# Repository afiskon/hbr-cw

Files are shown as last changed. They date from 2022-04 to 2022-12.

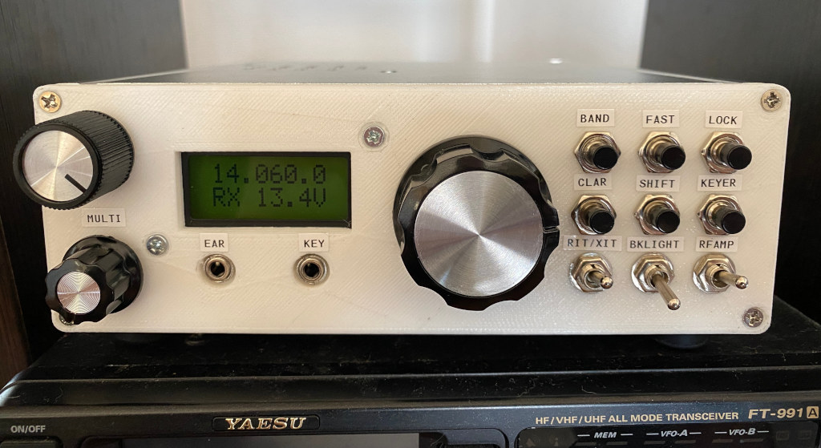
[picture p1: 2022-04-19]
images/front-panel.jpg

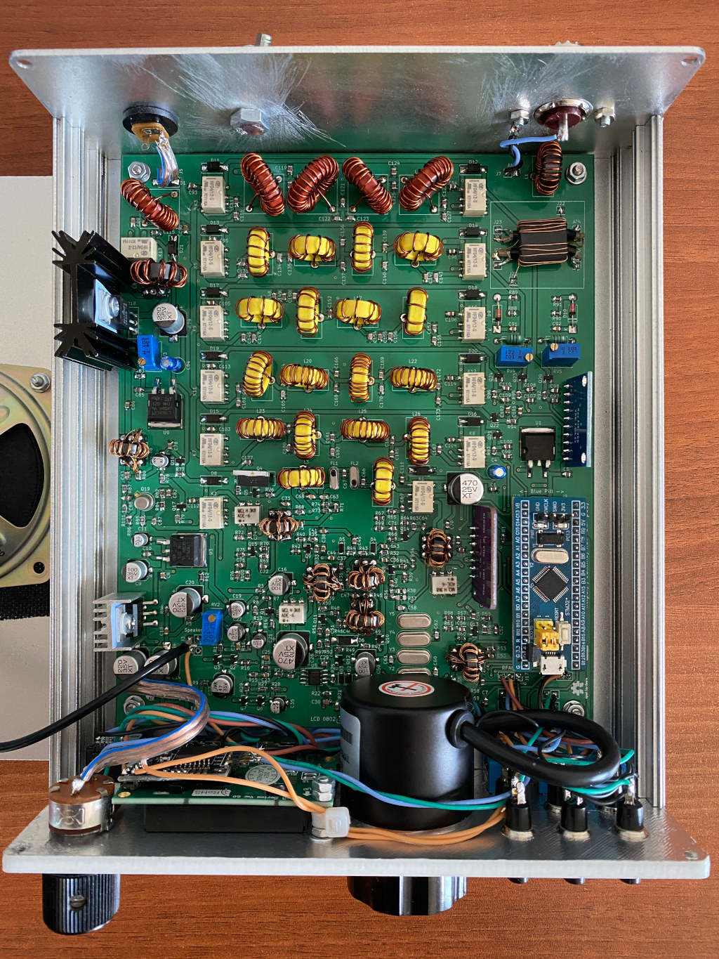
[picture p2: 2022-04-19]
images/internals.jpg

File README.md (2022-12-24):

# HBR/CW

**Update**: The project has some issues with spurious signals. This problem was addressed in [HBR/3B](https://github.com/afiskon/hbr-3b) and [HBR/8B](https://github.com/afiskon/hbr-8b).

All HF bands QRP CW transceiver

* Covers 80, 40, 30, 20, 17, 15, 12 and 10 meter bands
* IF-derived AGC
* Supports RIT, XIT and SHIFT
* 10-30 WPM Elekey-B type keyer + straight key mode
* Keyer settings are saved in EEPROM
* 5W class C power amplifier
* 9-pole low-pass filters
* HIGH SWR indicator
* Open-source firmware and hardware

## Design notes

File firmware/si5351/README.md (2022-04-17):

# stm32-si5351

HAL-based Si5351 driver for STM32.

Main respository: https://github.com/afiskon/stm32-si5351

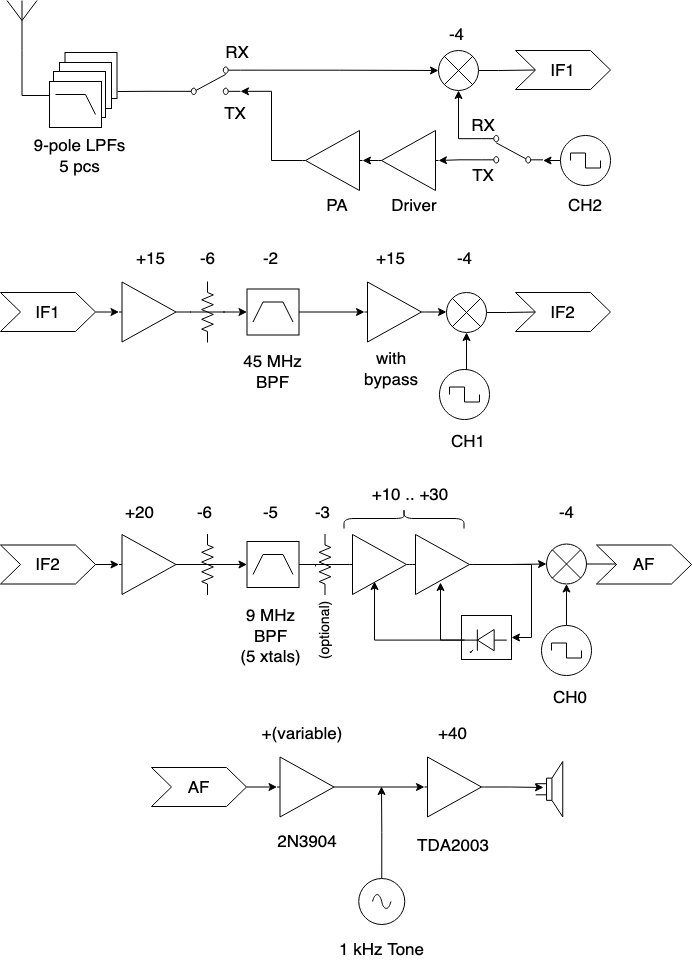
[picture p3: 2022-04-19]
block-diagram/hbr-cw-block-diagram.png

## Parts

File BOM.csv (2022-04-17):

Reference | Quantity | Value | Footprint
C1 C5 C6 C7 C8 C10 C15 C17 C29 C31 C33 C36 C37 C38 C39 C40 C41 C42 C43 C44 C45 C46 C47 C49 C51 C52 C53 C54 C55 C56 C64 C65 C69 C70 C71 C72 C73 C74 C75 C76 C78 C80 C81 C82 C83 C85 C86 C87 C88 C93 C94 C95 C96 C97 C98 C99 C100 C101 C102 C103 C104 C105 C106 C107 C108 C109 C110 C111 C112 C113 C114 C115 | 72 | 0.1u | Capacitor_SMD:C_0805_2012Metric_Pad1.15x1.40mm_HandSolder
C11 C21 C32 | 3 | 10u | Capacitor_SMD:CP_Elec_4x5.4
C119 C120 C124 C125 C179 C181 C185 | 7 | 820p | Capacitor_SMD:C_0805_2012Metric_Pad1.15x1.40mm_HandSolder
C12 C77 | 2 | 1u | Capacitor_SMD:CP_Elec_4x5.4
C121 C123 | 2 | 680p | Capacitor_SMD:C_0805_2012Metric_Pad1.15x1.40mm_HandSolder
C122 | 1 | 390p | Capacitor_SMD:C_0805_2012Metric_Pad1.15x1.40mm_HandSolder
C131 C143 C165 C170 | 4 | 150p | Capacitor_SMD:C_0805_2012Metric_Pad1.15x1.40mm_HandSolder
C132 C135 C139 C142 C150 C154 | 6 | 10p | Capacitor_SMD:C_0805_2012Metric_Pad1.15x1.40mm_HandSolder
C146 C148 C149 C155 C156 C158 | 6 | 100p | Capacitor_SMD:C_0805_2012Metric_Pad1.15x1.40mm_HandSolder
C147 C157 C162 C172 | 4 | 18p | Capacitor_SMD:C_0805_2012Metric_Pad1.15x1.40mm_HandSolder
C152 C161 C166 C168 C173 | 5 | 220p | Capacitor_SMD:C_0805_2012Metric_Pad1.15x1.40mm_HandSolder
C18 C24 C25 | 3 | 47n | Capacitor_SMD:C_0805_2012Metric_Pad1.15x1.40mm_HandSolder
C182 | 1 | 56p | Capacitor_SMD:C_0805_2012Metric_Pad1.15x1.40mm_HandSolder
C19 C22 | 2 | 22u | Capacitor_SMD:CP_Elec_5x5.4
C2 C26 | 2 | 470u | Capacitor_SMD:CP_Elec_10x10.5
C13 C14 C20 C79 | 4 | 220u | Capacitor_SMD:CP_Elec_8x10.5
C23 C91 C92 | 3 | 0.01u | Capacitor_SMD:C_0805_2012Metric_Pad1.15x1.40mm_HandSolder
C27 | 1 | 47u | Capacitor_SMD:CP_Elec_6.3x5.8
C28 C30 | 2 | 4.7n | Capacitor_SMD:C_0805_2012Metric_Pad1.15x1.40mm_HandSolder
C35 | 1 | 4.7u | Capacitor_SMD:CP_Elec_4x5.4
C4 C84 | 2 | 0.33u | Capacitor_THT:C_Radial_D5.0mm_H5.0mm_P2.00mm
C48 C116 C117 C127 C128 C177 C187 | 7 | 470p | Capacitor_SMD:C_0805_2012Metric_Pad1.15x1.40mm_HandSolder
C57 C58 C59 C60 C61 C62 C134 C136 C140 C164 C169 | 11 | 270p | Capacitor_SMD:C_0805_2012Metric_Pad1.15x1.40mm_HandSolder
C63 C66 C137 C180 C184 | 5 | 22p | Capacitor_SMD:C_0805_2012Metric_Pad1.15x1.40mm_HandSolder
C67 | 1 | 8p | Capacitor_SMD:C_0805_2012Metric_Pad1.15x1.40mm_HandSolder
C68 | 1 | 2p | Capacitor_SMD:C_0805_2012Metric_Pad1.15x1.40mm_HandSolder
C89 C90 | 2 | 1000p | Capacitor_SMD:C_0805_2012Metric_Pad1.15x1.40mm_HandSolder
C9 C16 C50 | 3 | 100u | Capacitor_SMD:CP_Elec_6.3x7.7
D1 D6 | 2 | SS14 | Diode_SMD:D_SMA_Handsoldering
D9 D10 | 2 | 1N34/D9B/D311 | Diode_THT:D_DO-41_SOD81_P10.16mm_Horizontal
D2 D3 D4 D5 | 4 | 1N4148W | Diode_SMD:D_SOD-123
D7 D8 D11 D12 D13 D14 D15 D16 D17 D18 D19 D20 D21 | 13 | M7 | Diode_SMD:D_SMA_Handsoldering
FL1 FL2 | 2 | 45M15B (*) | Crystal:Resonator-3Pin_W7.0mm_H2.5mm
H1 H2 H3 H4 | 4 | MH | MountingHole:MountingHole_3.2mm_M3_Pad_Via
J1 | 1 | ON/OFF | Connector_PinHeader_2.54mm:PinHeader_1x02_P2.54mm_Vertical
J10 | 1 | BluePill_Right | Connector_PinSocket_2.54mm:PinSocket_1x20_P2.54mm_Vertical
J11 | 1 | MAIN | Connector_PinHeader_2.54mm:PinHeader_1x04_P2.54mm_Vertical
J12 | 1 | BAND | Connector_PinHeader_2.54mm:PinHeader_1x02_P2.54mm_Vertical
J13 | 1 | LCD 0802 | Connector_PinHeader_2.54mm:PinHeader_1x04_P2.54mm_Vertical
J14 | 1 | RIT/XIT | Connector_PinSocket_2.54mm:PinSocket_1x03_P2.54mm_Vertical
J15 | 1 | FAST | Connector_PinHeader_2.54mm:PinHeader_1x02_P2.54mm_Vertical
J16 | 1 | LOCK | Connector_PinHeader_2.54mm:PinHeader_1x02_P2.54mm_Vertical
J17 | 1 | RFAMP | Connector_PinSocket_2.54mm:PinSocket_1x03_P2.54mm_Vertical
J18 | 1 | CLAR | Connector_PinHeader_2.54mm:PinHeader_1x02_P2.54mm_Vertical
J19 | 1 | Si5351 | Connector_PinHeader_2.54mm:PinHeader_1x07_P2.54mm_Vertical
J2 | 1 | SPEAKER_IN | Connector_PinHeader_2.54mm:PinHeader_1x02_P2.54mm_Vertical
J20 | 1 | SHIFT | Connector_PinHeader_2.54mm:PinHeader_1x02_P2.54mm_Vertical
J21 | 1 | KEYER | Connector_PinHeader_2.54mm:PinHeader_1x02_P2.54mm_Vertical
J22 | 1 | GND_B | Connector_PinHeader_2.54mm:PinHeader_1x01_P2.54mm_Vertical
J23 | 1 | STK_A | Connector_PinHeader_2.54mm:PinHeader_1x02_P2.54mm_Vertical
J24 | 1 | STK_B | Connector_PinHeader_2.54mm:PinHeader_1x02_P2.54mm_Vertical
J25 | 1 | STK_C | Connector_PinHeader_2.54mm:PinHeader_1x02_P2.54mm_Vertical
J26 | 1 | STK_D | Connector_PinHeader_2.54mm:PinHeader_1x02_P2.54mm_Vertical
J27 | 1 | ADS1115 | Connector_PinSocket_2.54mm:PinSocket_1x10_P2.54mm_Vertical
J28 | 1 | GND_C | Connector_PinHeader_2.54mm:PinHeader_1x01_P2.54mm_Vertical
J29 | 1 | VOL | Connector_PinSocket_2.54mm:PinSocket_1x03_P2.54mm_Vertical
J3 | 1 | SPEAKER_OUT | Connector_PinHeader_2.54mm:PinHeader_1x02_P2.54mm_Vertical
J4 | 1 | EAR | Connector_PinSocket_2.54mm:PinSocket_1x03_P2.54mm_Vertical
J5 | 1 | VCC | Connector_PinHeader_2.54mm:PinHeader_1x02_P2.54mm_Vertical
J6 | 1 | KEY | Connector_PinSocket_2.54mm:PinSocket_1x03_P2.54mm_Vertical
J7 | 1 | ANT | Connector_PinHeader_2.54mm:PinHeader_1x02_P2.54mm_Vertical
J8 | 1 | MULTI | Connector_PinHeader_2.54mm:PinHeader_1x04_P2.54mm_Vertical
J9 | 1 | BluePill_Left | Connector_PinSocket_2.54mm:PinSocket_1x20_P2.54mm_Vertical
K1 K2 K3 K4 K5 K6 K7 K8 K9 K10 K11 K12 K13 | 13 | HFD4/12S | Relay_SMD:Relay_DPDT_Omron_G6K-2F-Y
L1 | 1 | 23T @ FT50-43 | Inductor_THT:L_Toroid_Vertical_L13.0mm_W6.5mm_P5.60mm
L11 L14 | 2 | 0.5u | Inductor_THT:L_Toroid_Vertical_L13.0mm_W6.5mm_P5.60mm
L15 L18 | 2 | 0.35u | Inductor_THT:L_Toroid_Vertical_L13.0mm_W6.5mm_P5.60mm
L16 L17 | 2 | 0.4u | Inductor_THT:L_Toroid_Vertical_L13.0mm_W6.5mm_P5.60mm
L19 L22 | 2 | 0.7u | Inductor_THT:L_Toroid_Vertical_L13.0mm_W6.5mm_P5.60mm
L2 L12 L13 | 3 | 0.6u | Inductor_THT:L_Toroid_Vertical_L13.0mm_W6.5mm_P5.60mm
L20 L21 | 2 | 0.8u | Inductor_THT:L_Toroid_Vertical_L13.0mm_W6.5mm_P5.60mm
L23 L26 | 2 | 1.4u | Inductor_THT:L_Toroid_Vertical_L13.0mm_W6.5mm_P5.60mm
L24 L25 | 2 | 1.6u | Inductor_THT:L_Toroid_Vertical_L13.0mm_W6.5mm_P5.60mm
L3 | 1 | 0.65u | Inductor_THT:L_Toroid_Vertical_L13.0mm_W6.5mm_P5.60mm
L4 L5 | 2 | 1000 uH | Inductor_THT:L_Axial_L6.6mm_D2.7mm_P10.16mm_Horizontal_Vishay_IM-2
L6 | 1 | 3.6u | Inductor_THT:L_Radial_L12.6mm_W12.6mm_Px9.52mm_Py9.52mm_Pulse_LP-37
L7 L10 | 2 | 2.9u | Inductor_THT:L_Radial_L12.6mm_W12.6mm_Px9.52mm_Py9.52mm_Pulse_LP-37
L8 L9 | 2 | 3.2u | Inductor_THT:L_Radial_L12.6mm_W12.6mm_Px9.52mm_Py9.52mm_Pulse_LP-37
Q1 Q5 Q8 Q9 Q10 Q11 Q12 Q13 Q14 Q15 Q17 Q20 Q21 Q22 Q23 Q24 | 16 | MMBT3904 | Package_TO_SOT_SMD:SOT-23
Q16 | 1 | MMBT3906 | Package_TO_SOT_SMD:SOT-23
Q18 | 1 | RD15HVF1 | Package_TO_SOT_THT:TO-220-3_Vertical
Q19 | 1 | 2N2369A/КТ3142A (*) | Package_TO_SOT_THT:TO-18-3
Q2 Q3 Q6 Q7 | 4 | MMBF170 | Package_TO_SOT_SMD:SOT-23
Q4 | 1 | IRF4905 | Package_TO_SOT_THT:TO-220-3_Vertical
R1 | 1 | 15K | Resistor_SMD:R_0805_2012Metric_Pad1.15x1.40mm_HandSolder
R6 R9 R12 R27 R81 | 5 | 10 | Resistor_SMD:R_0805_2012Metric_Pad1.15x1.40mm_HandSolder
R13 | 1 | 47K | Resistor_SMD:R_0805_2012Metric_Pad1.15x1.40mm_HandSolder
R14 R39 R40 R43 R44 R50 R57 R65 R72 R78 R85 | 11 | 1K | Resistor_SMD:R_0805_2012Metric_Pad1.15x1.40mm_HandSolder
R15 | 1 | 51 | Resistor_SMD:R_0805_2012Metric_Pad1.15x1.40mm_HandSolder
R7 R10 R11 R16 R28 R83 | 6 | 2.2K | Resistor_SMD:R_0805_2012Metric_Pad1.15x1.40mm_HandSolder
R17 R19 R29 | 3 | 10K | Resistor_SMD:R_0805_2012Metric_Pad1.15x1.40mm_HandSolder
R2 | 1 | 2.7K | Resistor_SMD:R_0805_2012Metric_Pad1.15x1.40mm_HandSolder
R18 R21 | 2 | 33K | Resistor_SMD:R_0805_2012Metric_Pad1.15x1.40mm_HandSolder
R22 R32 R33 R46 R54 R63 R69 R82 | 8 | 3.3K | Resistor_SMD:R_0805_2012Metric_Pad1.15x1.40mm_HandSolder
R23 | 1 | 6.8K | Resistor_SMD:R_0805_2012Metric_Pad1.15x1.40mm_HandSolder
R25 | 1 | 8.2K | Resistor_SMD:R_0805_2012Metric_Pad1.15x1.40mm_HandSolder
R26 R77 R79 R92 R93 R94 R95 R96 | 8 | 470 | Resistor_SMD:R_0805_2012Metric_Pad1.15x1.40mm_HandSolder
R3 R30 R31 R88 R89 R90 R91 | 7 | 100 | Resistor_SMD:R_0805_2012Metric_Pad1.15x1.40mm_HandSolder
R34 R35 | 2 | 820 | Resistor_SMD:R_0805_2012Metric_Pad1.15x1.40mm_HandSolder
R36 | 1 | 18 | Resistor_SMD:R_0805_2012Metric_Pad1.15x1.40mm_HandSolder
R37 R38 | 2 | 300 | Resistor_SMD:R_0805_2012Metric_Pad1.15x1.40mm_HandSolder
R4 | 1 | 220 | Resistor_SMD:R_0805_2012Metric_Pad1.15x1.40mm_HandSolder
R41 R42 R51 R60 R66 R75 R86 | 7 | 68 | Resistor_SMD:R_0805_2012Metric_Pad1.15x1.40mm_HandSolder
R45 R53 R62 R68 R80 | 5 | 22 | Resistor_SMD:R_0805_2012Metric_Pad1.15x1.40mm_HandSolder
R48 R55 R64 R70 R84 | 5 | 1.3K | Resistor_SMD:R_0805_2012Metric_Pad1.15x1.40mm_HandSolder
R47 R49 | 2 | 4.7K | Resistor_SMD:R_0805_2012Metric_Pad1.15x1.40mm_HandSolder
R5 | 1 | 680 | Resistor_SMD:R_0805_2012Metric_Pad1.15x1.40mm_HandSolder
R52 R61 R67 R76 R87 R97 R98 R99 R100 R101 | 10 | 12 | Resistor_SMD:R_0805_2012Metric_Pad1.15x1.40mm_HandSolder
R56 R71 | 2 | 36 | Resistor_SMD:R_0805_2012Metric_Pad1.15x1.40mm_HandSolder
R58 R59 R73 R74 | 4 | 150 | Resistor_SMD:R_0805_2012Metric_Pad1.15x1.40mm_HandSolder
R8 R20 R24 | 3 | 100K | Resistor_SMD:R_0805_2012Metric_Pad1.15x1.40mm_HandSolder
RV2 RV3 | 2 | 10K | Potentiometer_THT:Potentiometer_Bourns_3296W_Vertical
RV4 RV5 | 2 | 1K | Potentiometer_THT:Potentiometer_Bourns_3296W_Vertical
SYM1 | 1 | Logo_Open_Hardware_Small | Symbol:OSHW-Logo2_9.8x8mm_SilkScreen
SYM2 | 1 | SYM_Radio_Waves_Large | Symbol:KiCad-Logo_5mm_SilkScreen
T1 T2 T3 T4 T5 T6 T8 | 7 | FT37-43 | Package_DIP:DIP-6_W7.62mm
T7 | 1 | FT50-43 | Package_DIP:DIP-6_W7.62mm
U1 U9 | 2 | L7805 | Package_TO_SOT_SMD:TO-263-2
U2 | 1 | 24LC64 | Package_SO:SO-8_5.3x6.2mm_P1.27mm
U3 | 1 | L7809 | Package_TO_SOT_SMD:TO-263-2
U4 | 1 | TDA2003 | Package_TO_SOT_THT:TO-220-5_P3.4x3.7mm_StaggerOdd_Lead3.8mm_Vertical
U5 | 1 | NE5532 | Package_SO:SOIC-8_5.23x5.23mm_P1.27mm
U6 U7 U8 | 3 | ADE-6 | RF_Mini-Circuits:Mini-Circuits_CD542_LandPatternPL-052
Y1 Y2 Y3 Y4 Y5 | 5 | 9Mhz | Crystal:Crystal_HC49-U_Vertical
~ | 1 | BN61-202
~ | 1 | MCP100-315DI

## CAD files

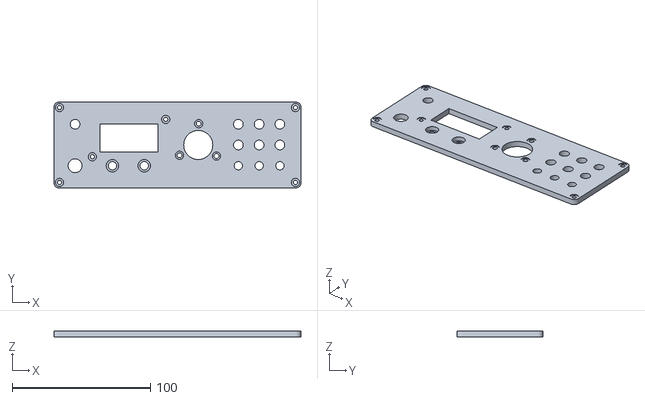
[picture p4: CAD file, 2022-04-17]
front-panel/optical-encoders.stl
178.5 x 62.0 x 4.00

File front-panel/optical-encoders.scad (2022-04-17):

W = 178.5;
H = 62;
t = 4;

pot_dia = 7; // volume control
jack_dia = 6; // 3.5 mm jack
jack_nut_dia = 9;
jack_nut_height = t-1;
button_dia = 7; // button
toggle_dia = 6; // toggle switch
corner_dia = 7;
screw_dia = 3;
screw_offset = 4;
screw2_dia = 6;
screw2_height = 0.5;
eps = 0.01;

main_enc_dia = 21;
main_enc_screws_dia = 15;
main_enc_screws_dist = 7;
main_enc_rotate_delta = 12;
main_enc_screw_dia = 3.5;
multi_enc_dia = 10;

// LCD info
LCD_W = 58;
LCD_H = 32;
lcd_offset_y = 8;
lcd_offset_x = 6;
lcd_h = LCD_H - lcd_offset_x*2;
lcd_w = LCD_W - lcd_offset_y*2;

hole_dia = 3;
hole_offset_x = 1+hole_dia/2;
hole_offset_y = 1+hole_dia/2;

module rounded_cube( width, height, dia, t ) {
    translate([-width/2, -height/2, -t/2])
        linear_extrude(height = t)
            hull() {
                translate([dia/2, dia/2, 0])
                    circle(d = dia, $fn = 25, center = true);
                translate([dia/2, height - dia/2, 0 ])
                    circle(d = dia, $fn = 25, center = true);
                translate([width - dia/2, height - dia/2, 0])
                    circle(d = dia, $fn = 25, center = true);
                translate([width - dia/2, dia/2, 0])
                    circle(d = dia, $fn = 25, center = true);
            }
}

difference() {
    rounded_cube(W, H, corner_dia, t);
    
    // screws
    translate([-W/2+screw_offset, H/2-screw_offset, 0]) {
        cylinder(d = screw_dia, h = t*2, $fn = 25, center = true);
        translate([0, 0, (t-screw2_height)/2+eps])
            cylinder(d = screw2_dia, h = screw2_height+eps, $fn = 25, center = true);
    }
    translate([-W/2+screw_offset, -H/2+screw_offset, 0]) {
        cylinder(d = screw_dia, h = t*2, $fn = 25, center = true);
        translate([0, 0, (t-screw2_height)/2+eps])
            cylinder(d = screw2_dia, h = screw2_height+eps, $fn = 25, center = true);
    }
    translate([W/2-screw_offset, H/2-screw_offset, 0]) {
        cylinder(d = screw_dia, h = t*2, $fn = 25, center = true);
        translate([0, 0, (t-screw2_height)/2+eps])
            cylinder(d = screw2_dia, h = screw2_height+eps, $fn = 25, center = true);
    }
    
    translate([W/2-screw_offset, -H/2+screw_offset, 0]) {
        cylinder(d = screw_dia, h = t*2, $fn = 25, center = true);
        translate([0, 0, (t-screw2_height)/2+eps])
            cylinder(d = screw2_dia, h = screw2_height+eps, $fn = 25, center = true);
    }
    
    // volume control and MULTI knob    
    translate([-74, 15, 0])
        cylinder(d = pot_dia, h = t*2, $fn = 50, center = true);
    translate([-74, -15, 0])
        cylinder(d = multi_enc_dia, h = t*2, $fn = 50, center = true);
    
    // LCD
    translate([-35, 5, 0]) rotate([0, 0, 90]) {
        cube([lcd_h, lcd_w, t*2], center=true);
        /*translate([LCD_H/2-hole_offset_x, LCD_W/2-hole_offset_y, 0]) {
            cylinder(h = t*2, d = hole_dia, center = true, $fn = 25);
            translate([0, 0, (t-screw2_height)/2+eps])
                cylinder(d = screw2_dia, h = screw2_height+eps, $fn = 25, center = true);
        }*/
        translate([-LCD_H/2+hole_offset_x, LCD_W/2-hole_offset_y, 0]) {
            cylinder(h = t*2, d = hole_dia, center = true, $fn = 25);
            translate([0, 0, (t-screw2_height)/2+eps])
                cylinder(d = screw2_dia, h = screw2_height+eps, $fn = 25, center = true);
        }
        translate([LCD_H/2-hole_offset_x, -LCD_W/2+hole_offset_y, 0]) {
            cylinder(h = t*2, d = hole_dia, center = true, $fn = 25);
            translate([0, 0, (t-screw2_height)/2+eps])
                cylinder(d = screw2_dia, h = screw2_height+eps, $fn = 25, center = true);
        }
        /* translate([-LCD_H/2+hole_offset_x, -LCD_W/2+hole_offset_y, 0]) {
            cylinder(h = t*2, d = hole_dia, center = true, $fn = 25);
            translate([0, 0, (t-screw2_height)/2+eps])
                cylinder(d = screw2_dia, h = screw2_height+eps, $fn = 25, center = true);
        } */
    }
    
    // 3.5 mm jacks
    translate([-24, -15, 0]) {
        cylinder(d = jack_dia, h = t*2, $fn = 50, center = true);
        translate([0, 0, (t - jack_nut_height)/2+eps])
            cylinder(d = jack_nut_dia, h = jack_nut_height, $fn = 50, center = true);
    }
    translate([-47, -15, 0]) {
        cylinder(d = jack_dia, h = t*2, $fn = 50, center = true);
        translate([0, 0, (t - jack_nut_height)/2+eps])
            cylinder(d = jack_nut_dia, h = jack_nut_height, $fn = 50, center = true);
    }
    
    // Main dial
    translate([15, 0, 0]) {
        cylinder(d = main_enc_dia, h = t*2, $fn = 50, center = true);
        
        rotate([0,0,120*0 + main_enc_rotate_delta]) {
            translate([main_enc_screws_dist/2, main_enc_screws_dia, 0]) {
                cylinder(d = main_enc_screw_dia, h = t*2, $fn = 25, center = true);
                translate([0, 0, (t-screw2_height)/2+eps])
                    cylinder(d = screw2_dia, h = screw2_height+eps, $fn = 25, center = true);
            }
            
            /*translate([-main_enc_screws_dist/2, main_enc_screws_dia,0]) {
                cylinder(d = main_enc_screw_dia, h = t*2, $fn = 25, center = true);
                translate([0, 0, (t-screw2_height)/2+eps])
                    cylinder(d = screw2_dia, h = screw2_height+eps, $fn = 25, center = true);
            }*/
        }
        
        rotate([0,0,120*1 + main_enc_rotate_delta]) {
            translate([main_enc_screws_dist/2, main_enc_screws_dia, 0]) {
                cylinder(d = main_enc_screw_dia, h = t*2, $fn = 25, center = true);
                translate([0, 0, (t-screw2_height)/2+eps])
                    cylinder(d = screw2_dia, h = screw2_height+eps, $fn = 25, center = true);
            }
            
            /*translate([-main_enc_screws_dist/2, main_enc_screws_dia,0]) {
                cylinder(d = main_enc_screw_dia, h = t*2, $fn = 25, center = true);
                translate([0, 0, (t-screw2_height)/2+eps])
                    cylinder(d = screw2_dia, h = screw2_height+eps, $fn = 25, center = true);
            }*/
        }
        
        rotate([0,0,120*2 + main_enc_rotate_delta]) {
            translate([main_enc_screws_dist/2, main_enc_screws_dia, 0]) {
                cylinder(d = main_enc_screw_dia, h = t*2, $fn = 25, center = true);
                translate([0, 0, (t-screw2_height)/2+eps])
                    cylinder(d = screw2_dia, h = screw2_height+eps, $fn = 25, center = true);
            }
            
            /*translate([-main_enc_screws_dist/2, main_enc_screws_dia,0]) {
                cylinder(d = main_enc_screw_dia, h = t*2, $fn = 25, center = true);
                translate([0, 0, (t-screw2_height)/2+eps])
                    cylinder(d = screw2_dia, h = screw2_height+eps, $fn = 25, center = true);
            }*/
        }
    }
    
    // Buttons and toggles
    translate([74, 0, 0]) {
        cylinder(d = button_dia, h = t*2, $fn = 50, center = true);
        
        translate([0, 15, 0])
            cylinder(d = button_dia, h = t*2, $fn = 50, center = true);
        
        translate([0, -15, 0])
            cylinder(d = toggle_dia, h = t*2, $fn = 50, center = true);
    }
    
    translate([74-15, 0, 0]) {
        cylinder(d = button_dia, h = t*2, $fn = 50, center = true);
        
        translate([0, 15, 0])
            cylinder(d = button_dia, h = t*2, $fn = 50, center = true);
        
        translate([0, -15, 0])
            cylinder(d = toggle_dia, h = t*2, $fn = 50, center = true);
    }
    
    translate([74-15*2, 0, 0]) {
        cylinder(d = button_dia, h = t*2, $fn = 50, center = true);
        
        translate([0, 15, 0])
            cylinder(d = button_dia, h = t*2, $fn = 50, center = true);
        
        translate([0, -15, 0])
            cylinder(d = toggle_dia, h = t*2, $fn = 50, center = true);
    }
}

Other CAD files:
front-panel/pec11r-encoders.stl
front-panel/pec11r-encoders.scad

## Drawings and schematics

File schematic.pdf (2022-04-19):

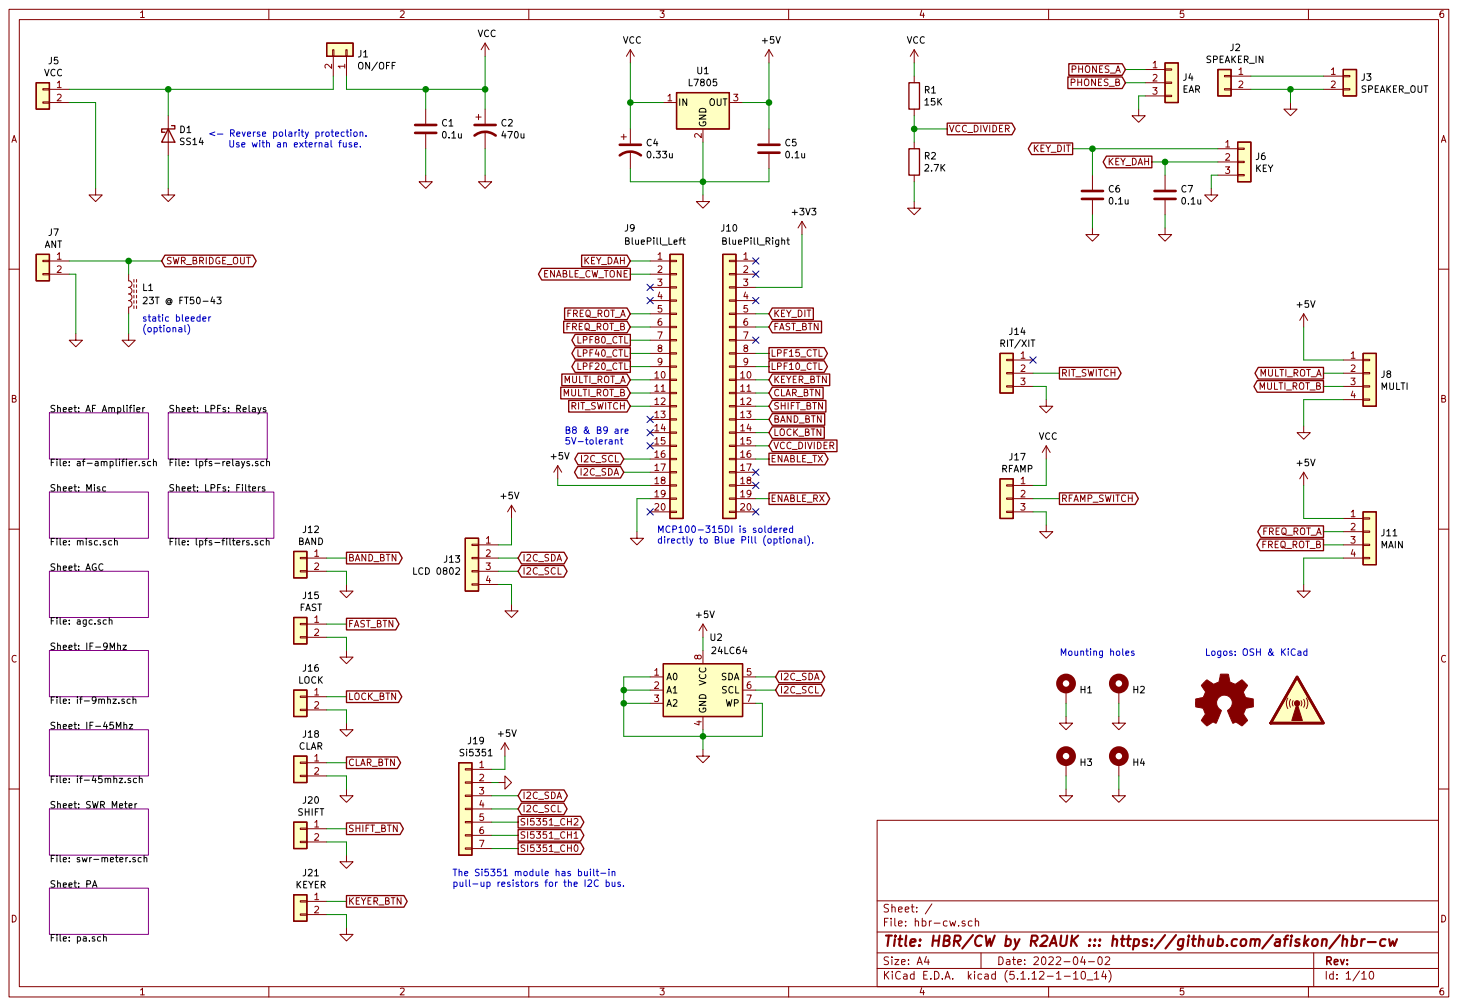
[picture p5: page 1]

< Reverse polarity protection.
Use with an external fuse.

File: af-amplifier.sch Sheet: Misc File: misc.sch Sheet: AGC

File: lpfs-relays.sch Sheet: LPFs: Filters File: lpfs-filters.sch

File: agc.sch Sheet: IF-9Mhz File: if-9mhz.sch Sheet: IF-45Mhz File: if-45mhz.sch Sheet: PA

4 SDA 5 SCL 6 WP 7 VCC

File: pa.sch Sheet: SWR Meter File: swr-meter.sch

pull-up resistors for the I2C bus.

File: hbr-cw.sch Sheet: /
Id: 1/10 Title: HBR/CW by R2AUK ::: https://github.com/afiskon/hbr-cw

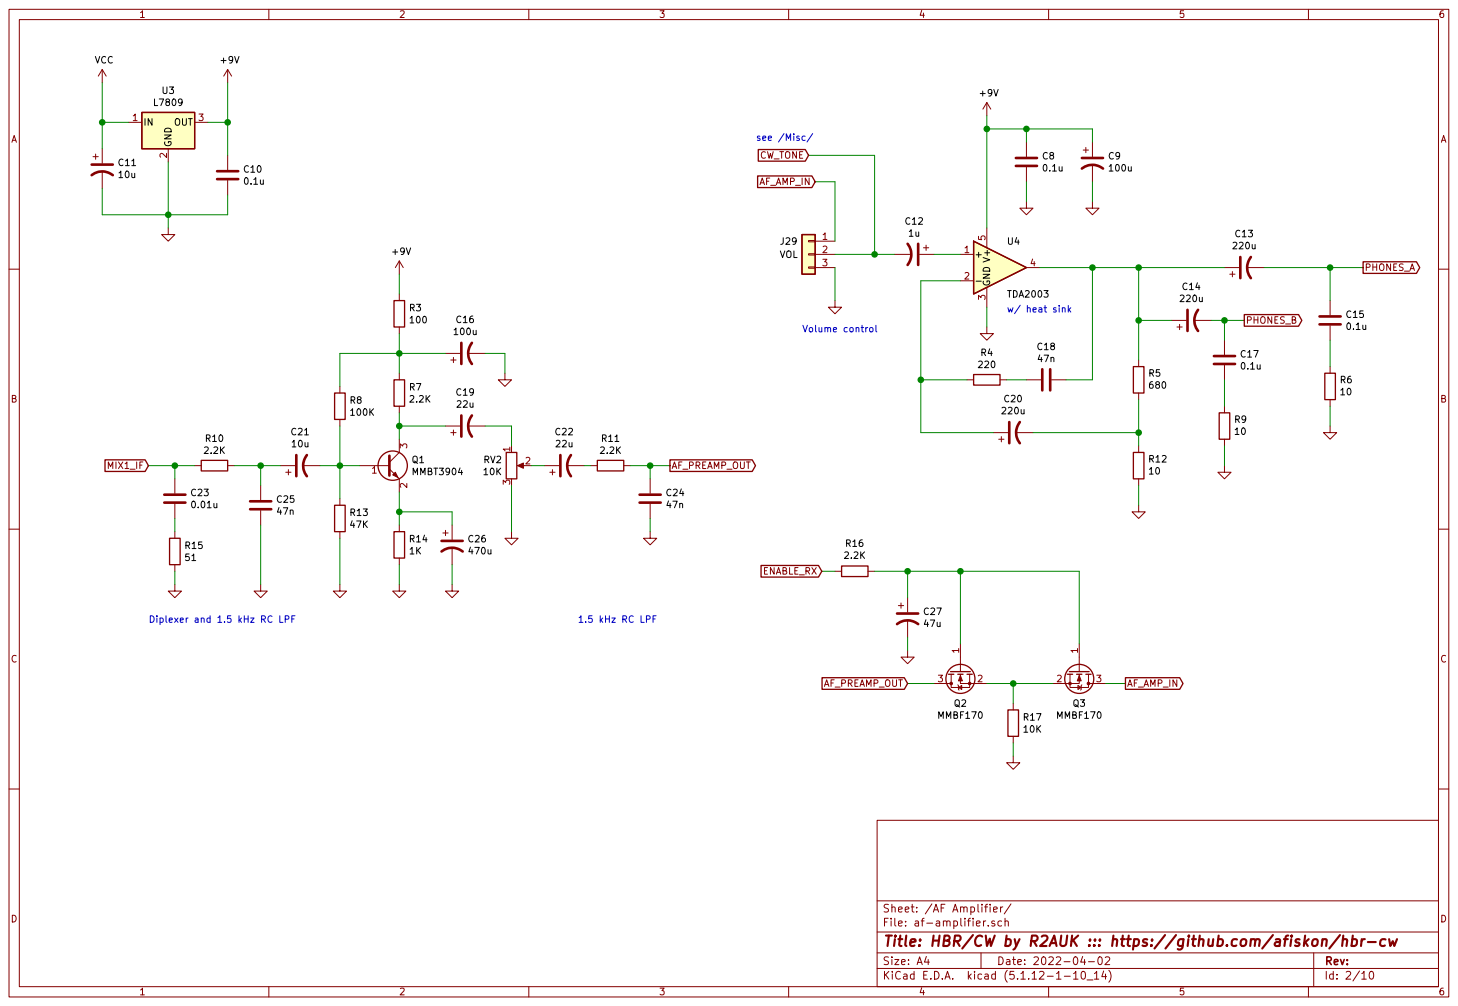
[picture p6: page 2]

see /Misc/ Volume control
CW_TONE

Sheet: /AF Amplifier/
File: af-amplifier.sch
Id: 2/10 Title: HBR/CW by R2AUK ::: https://github.com/afiskon/hbr-cw

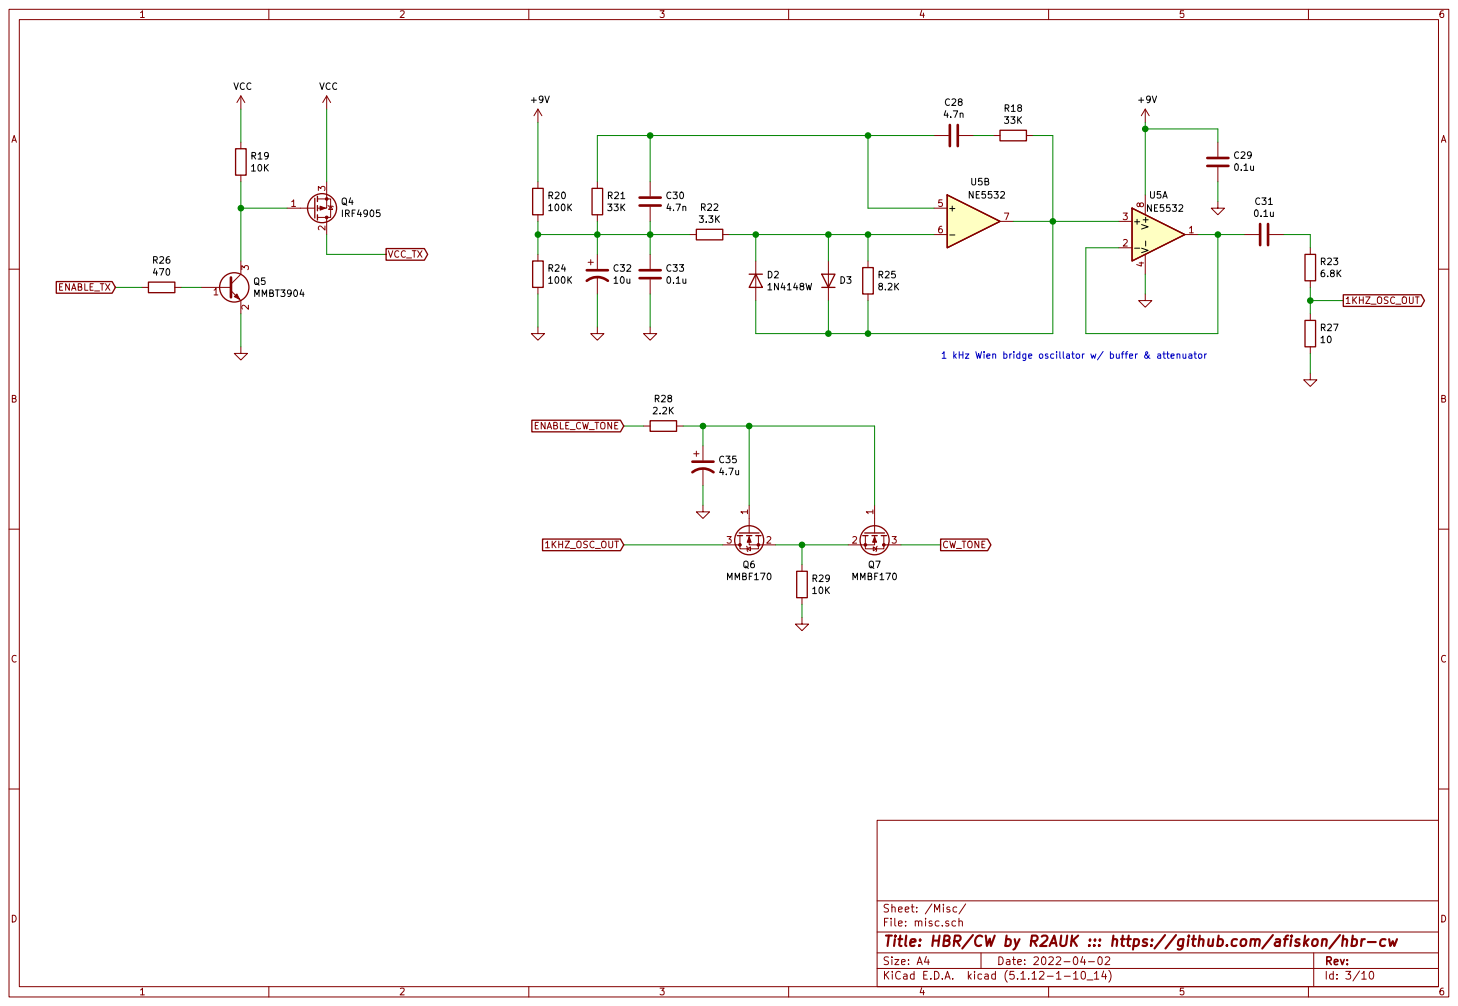
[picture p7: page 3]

1 kHz Wien bridge oscillator w/ buffer & attenuator

File: misc.sch Sheet: /Misc/
Id: 3/10 Title: HBR/CW by R2AUK ::: https://github.com/afiskon/hbr-cw

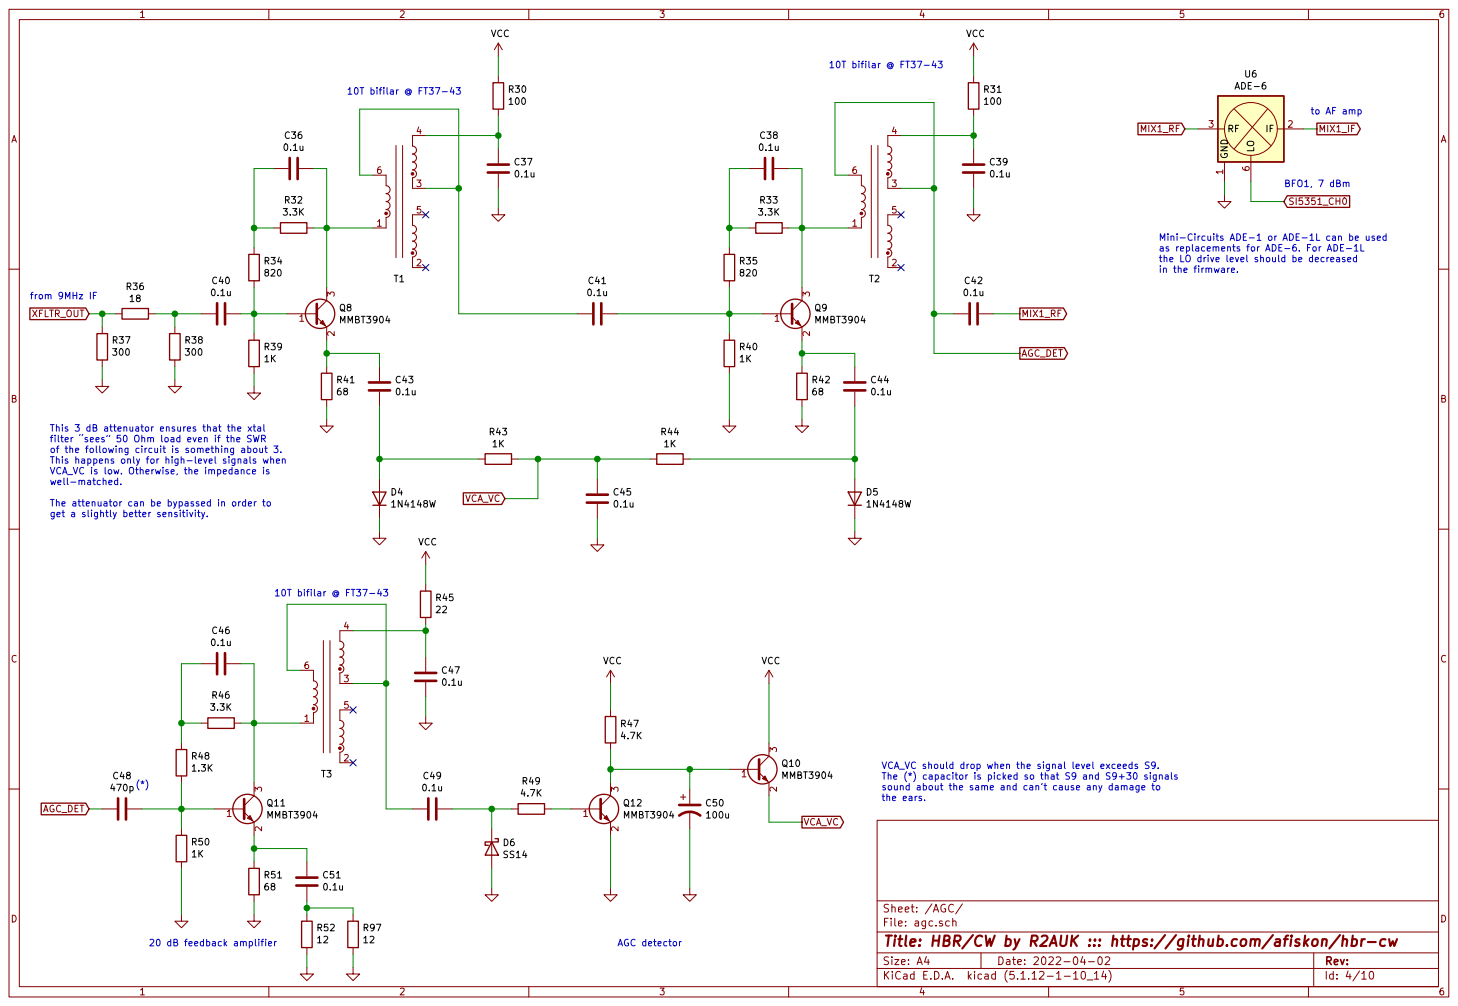
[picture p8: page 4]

in the firmware. 10T bifilar @ FT37-43

Mini-Circuits ADE-1 or ADE-1L can be used
as replacements for ADE-6. For ADE-1L
the LO drive level should be decreased

This 3 dB attenuator ensures that the xtal filter sees 50 Ohm load even if the SWR

of the following circuit is something about 3.
This happens only for high-level signals when
VCA_VC is low. Otherwise, the impedance is well-matched. The attenuator can be bypassed in order to

File: agc.sch Sheet: /AGC/ R46

VCA_VC should drop when the signal level exceeds S9.
The (*) capacitor is picked so that S9 and S9+30 signals
sound about the same and cant cause any damage to
the ears.

Id: 4/10 Title: HBR/CW by R2AUK ::: https://github.com/afiskon/hbr-cw

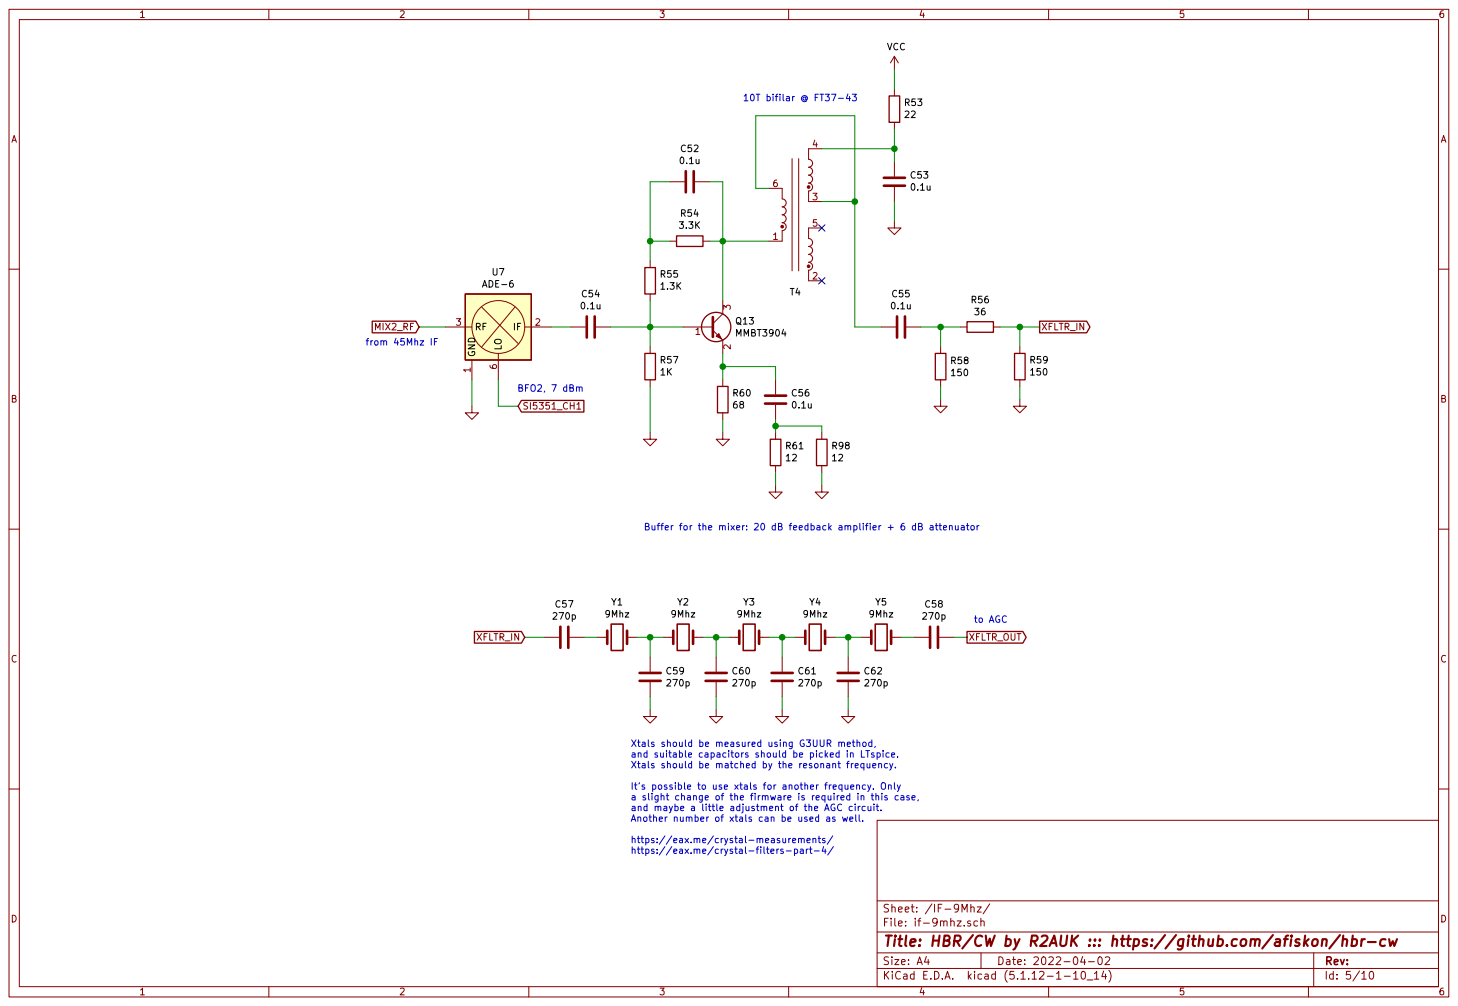
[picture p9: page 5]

File: if-9mhz.sch Sheet: /IF-9Mhz/ GND

Buffer for the mixer: 20 dB feedback amplifier + 6 dB attenuator

Xtals should be measured using G3UUR method,
and suitable capacitors should be picked in LTspice.
Xtals should be matched by the resonant frequency.

Its possible to use xtals for another frequency. Only
a slight change of the firmware is required in this case,
and maybe a little adjustment of the AGC circuit. Another number of xtals can be used as well. https://eax.me/crystal-measurements/

https://eax.me/crystal-filters-part-4/

Id: 5/10 Title: HBR/CW by R2AUK ::: https://github.com/afiskon/hbr-cw

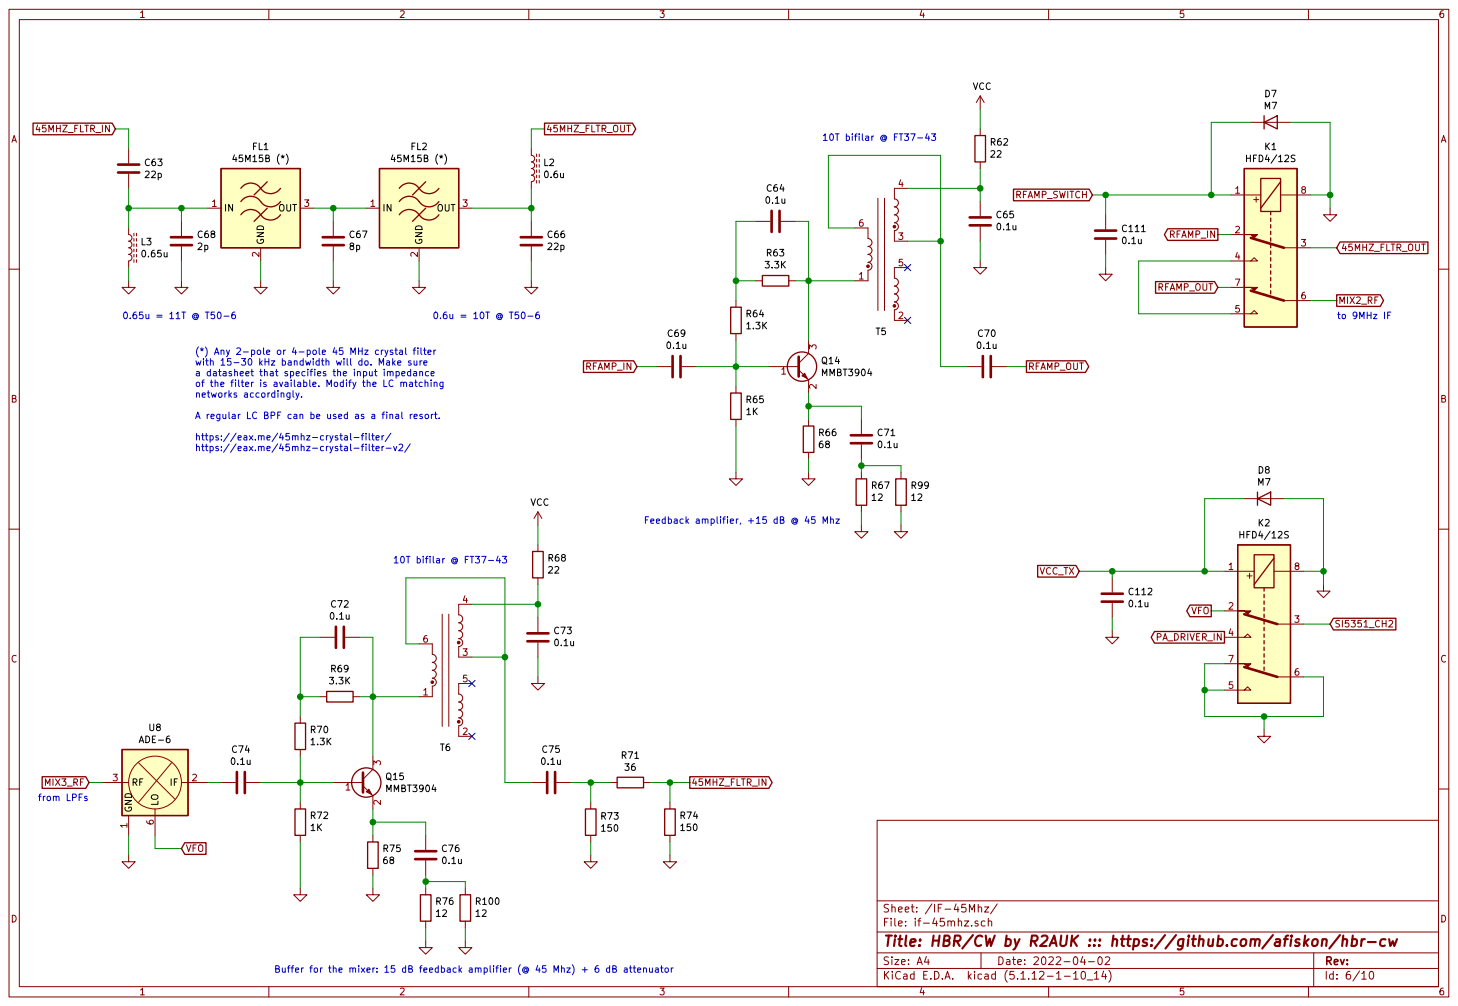
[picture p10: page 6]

(*) Any 2-pole or 4-pole 45 MHz crystal filter with 15-30 kHz bandwidth will do. Make sure

a datasheet that specifies the input impedance
of the filter is available. Modify the LC matching
networks accordingly.

A regular LC BPF can be used as a final resort.

https://eax.me/45mhz-crystal-filter/

Feedback amplifier, +15 dB @ 45 Mhz

10T bifilar @ FT37-43 Buffer for the mixer: 15 dB feedback amplifier (@ 45 Mhz) + 6 dB attenuator

Id: 6/10 Title: HBR/CW by R2AUK ::: https://github.com/afiskon/hbr-cw

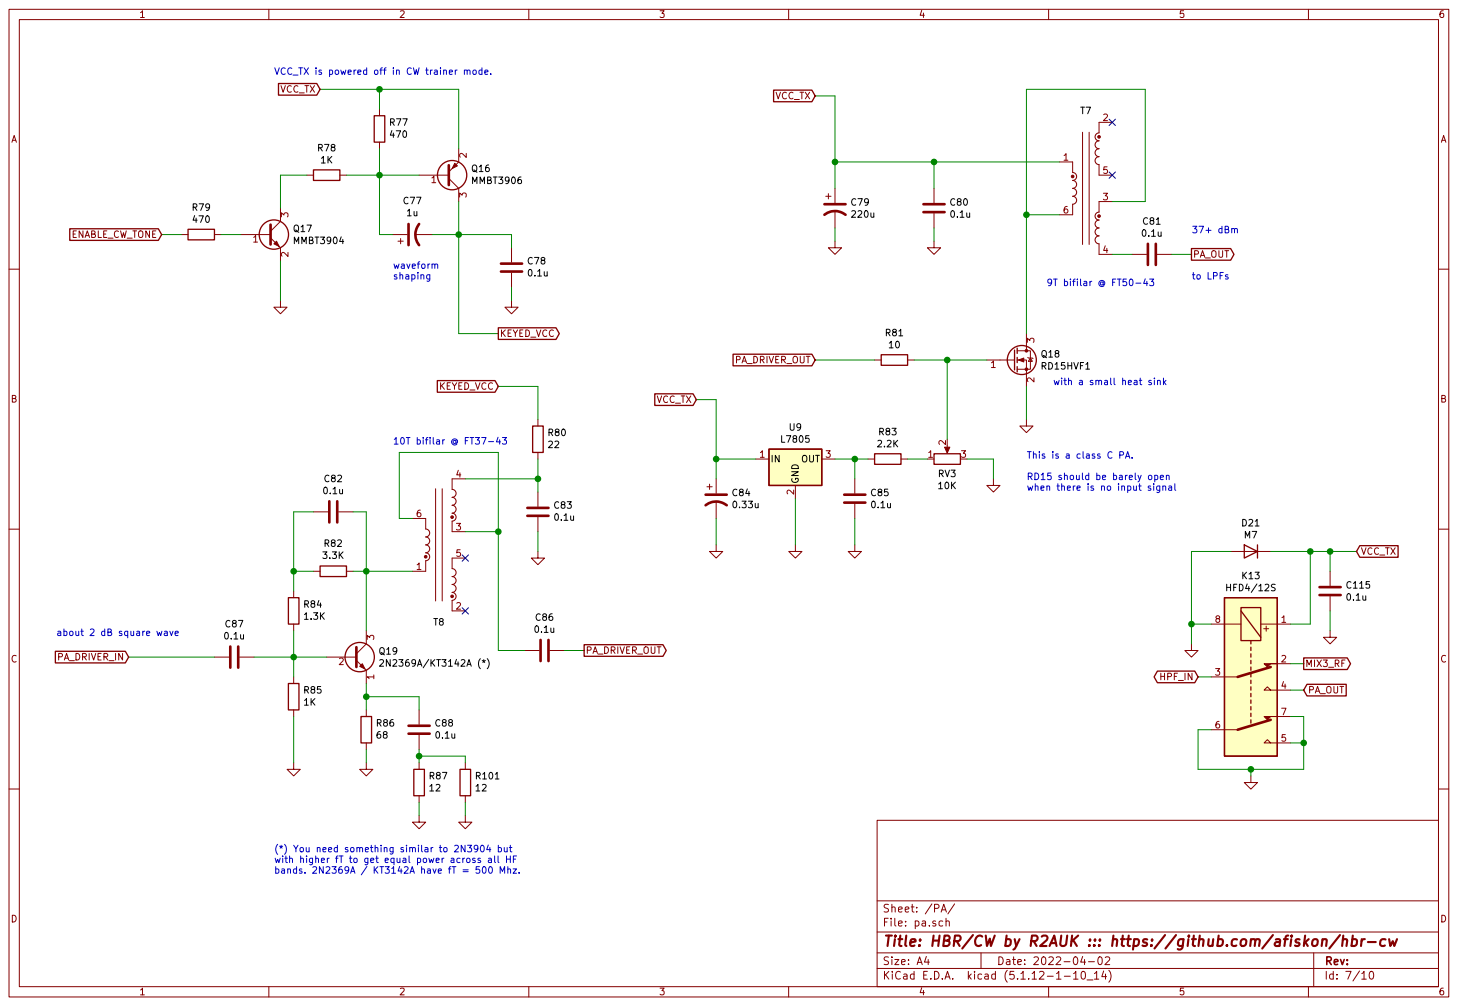
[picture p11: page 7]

when there is no input signal

about 2 dB square wave

(*) You need something similar to 2N3904 but
with higher fT to get equal power across all HF
bands. 2N2369A / KT3142A have fT = 500 Mhz.

Id: 7/10 Title: HBR/CW by R2AUK ::: https://github.com/afiskon/hbr-cw

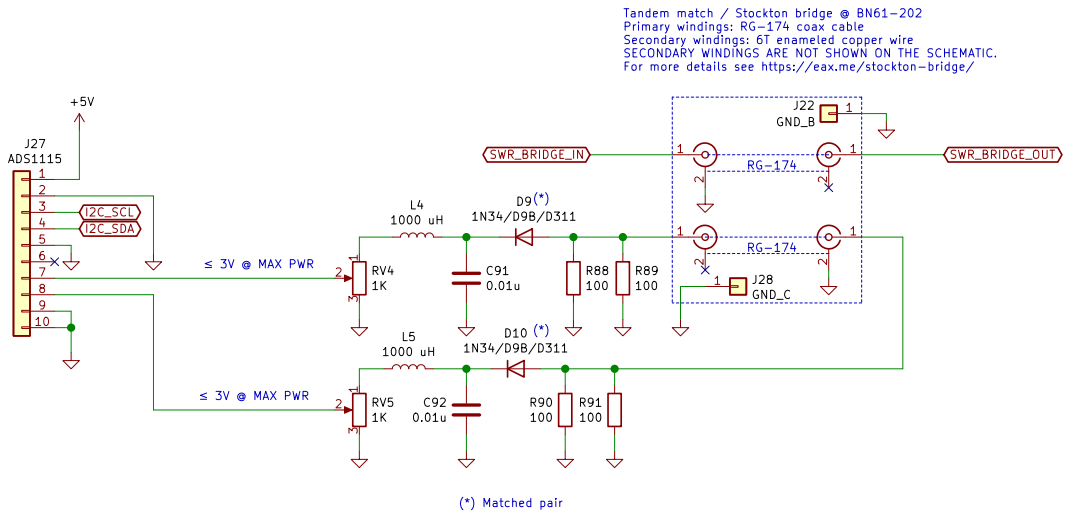
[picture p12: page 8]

Tandem match / Stockton bridge @ BN61-202
Primary windings: RG-174 coax cable
Secondary windings: 6T enameled copper wire SECONDARY WINDINGS ARE NOT SHOWN ON THE SCHEMATIC. For more details see https://eax.me/stockton-bridge/

File: swr-meter.sch Sheet: /SWR Meter/
Id: 8/10 Title: HBR/CW by R2AUK ::: https://github.com/afiskon/hbr-cw

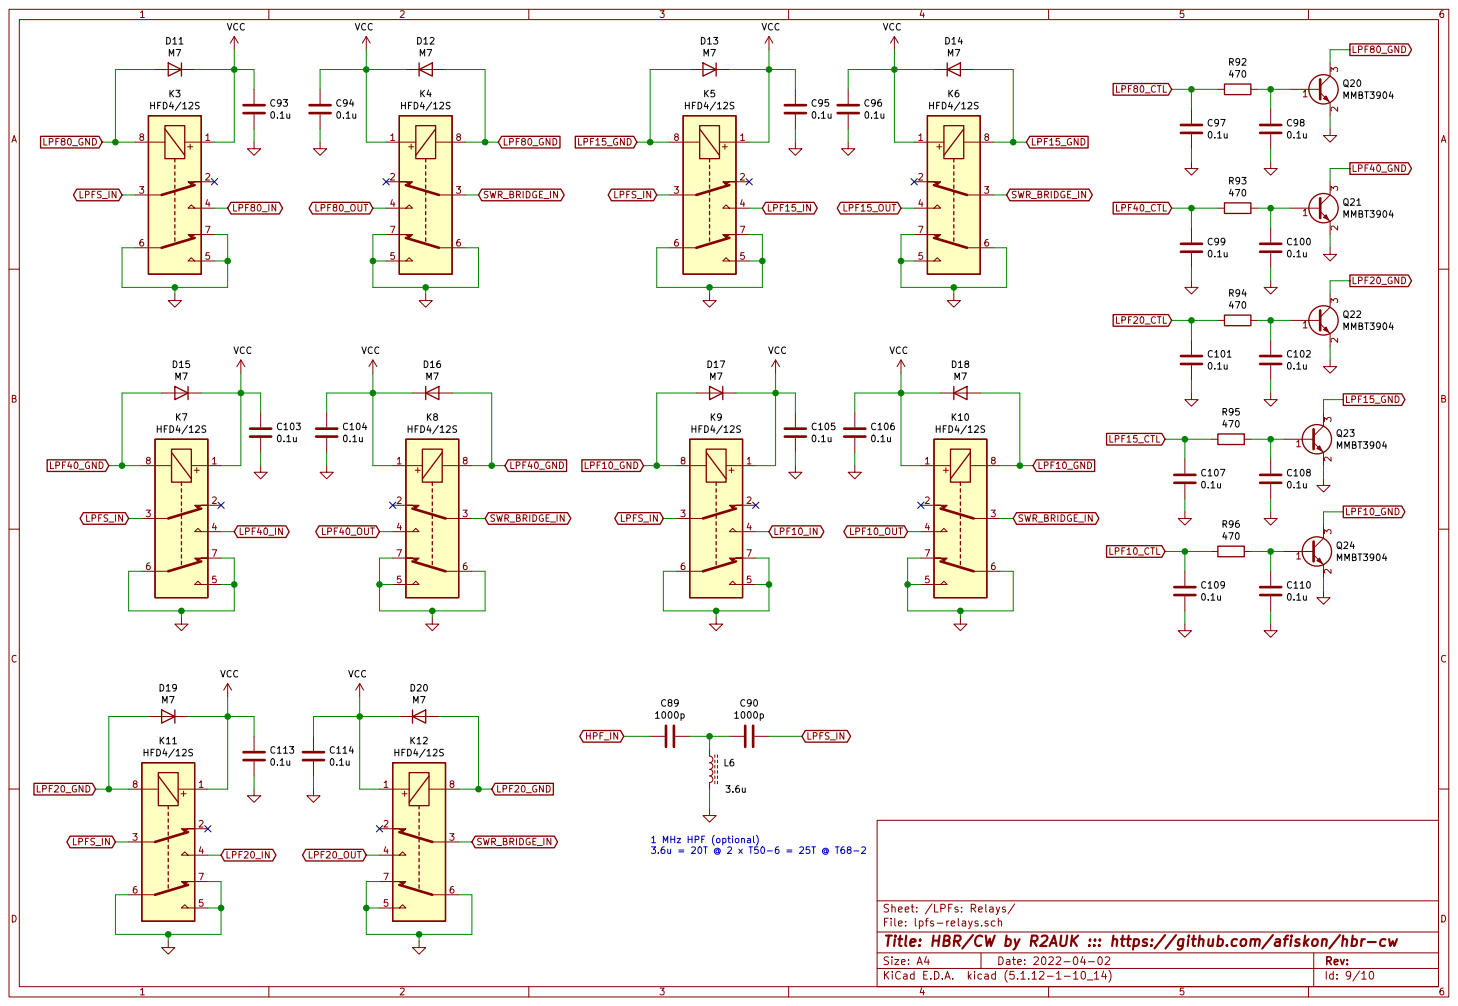
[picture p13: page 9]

Sheet: /LPFs: Relays/
File: lpfs-relays.sch
Id: 9/10 Title: HBR/CW by R2AUK ::: https://github.com/afiskon/hbr-cw

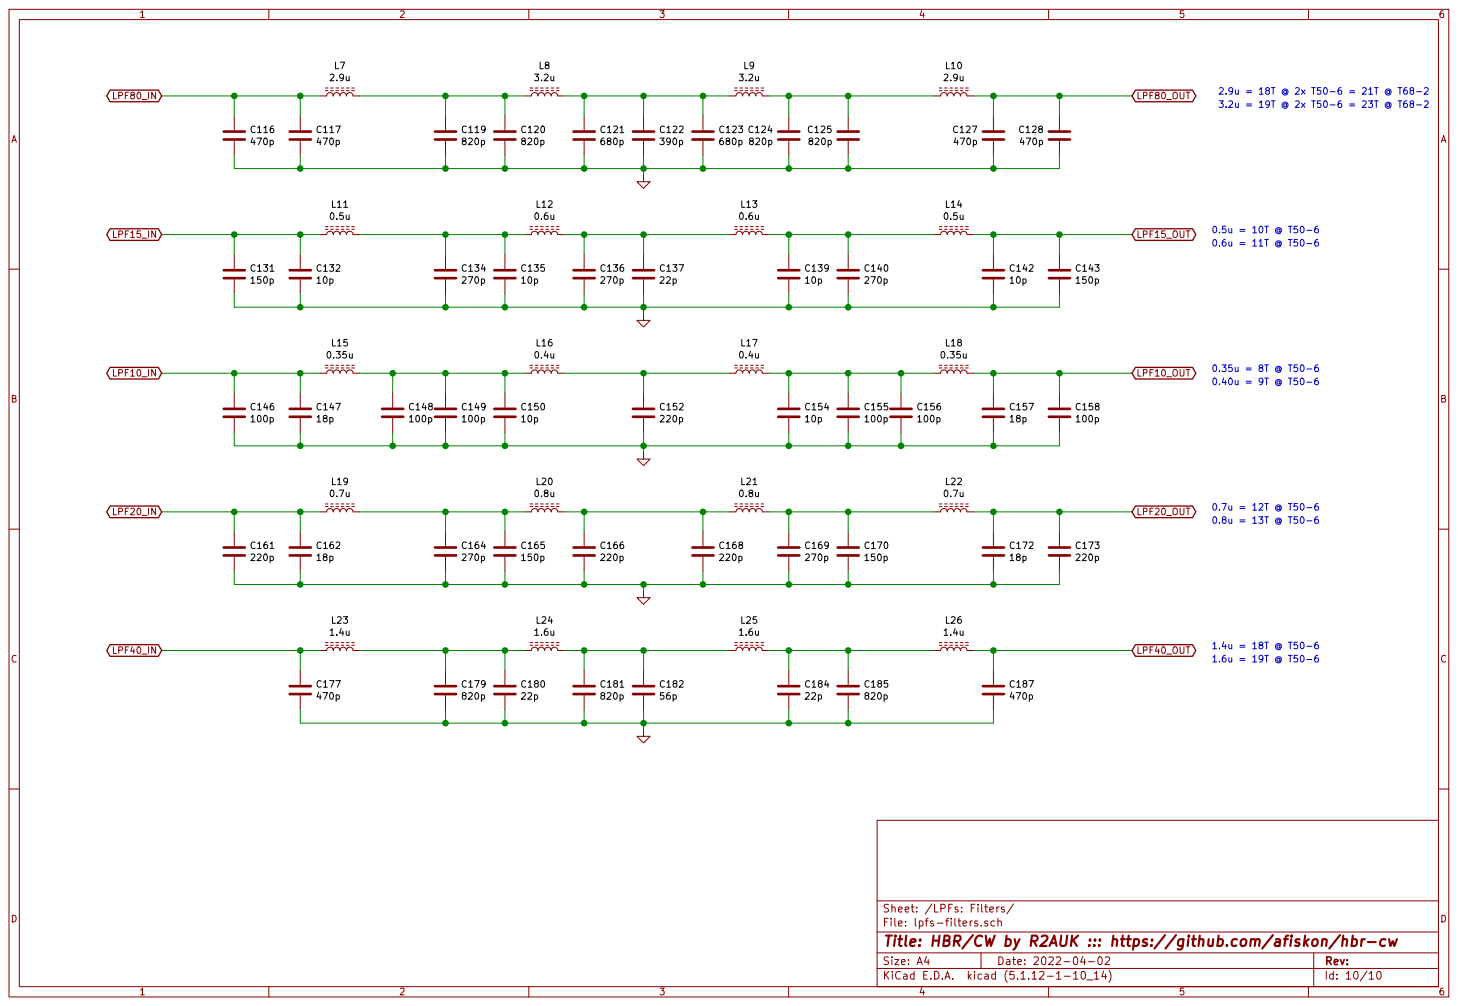
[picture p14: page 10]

File: lpfs-filters.sch Sheet: /LPFs: Filters/ C168

Id: 10/10 Title: HBR/CW by R2AUK ::: https://github.com/afiskon/hbr-cw

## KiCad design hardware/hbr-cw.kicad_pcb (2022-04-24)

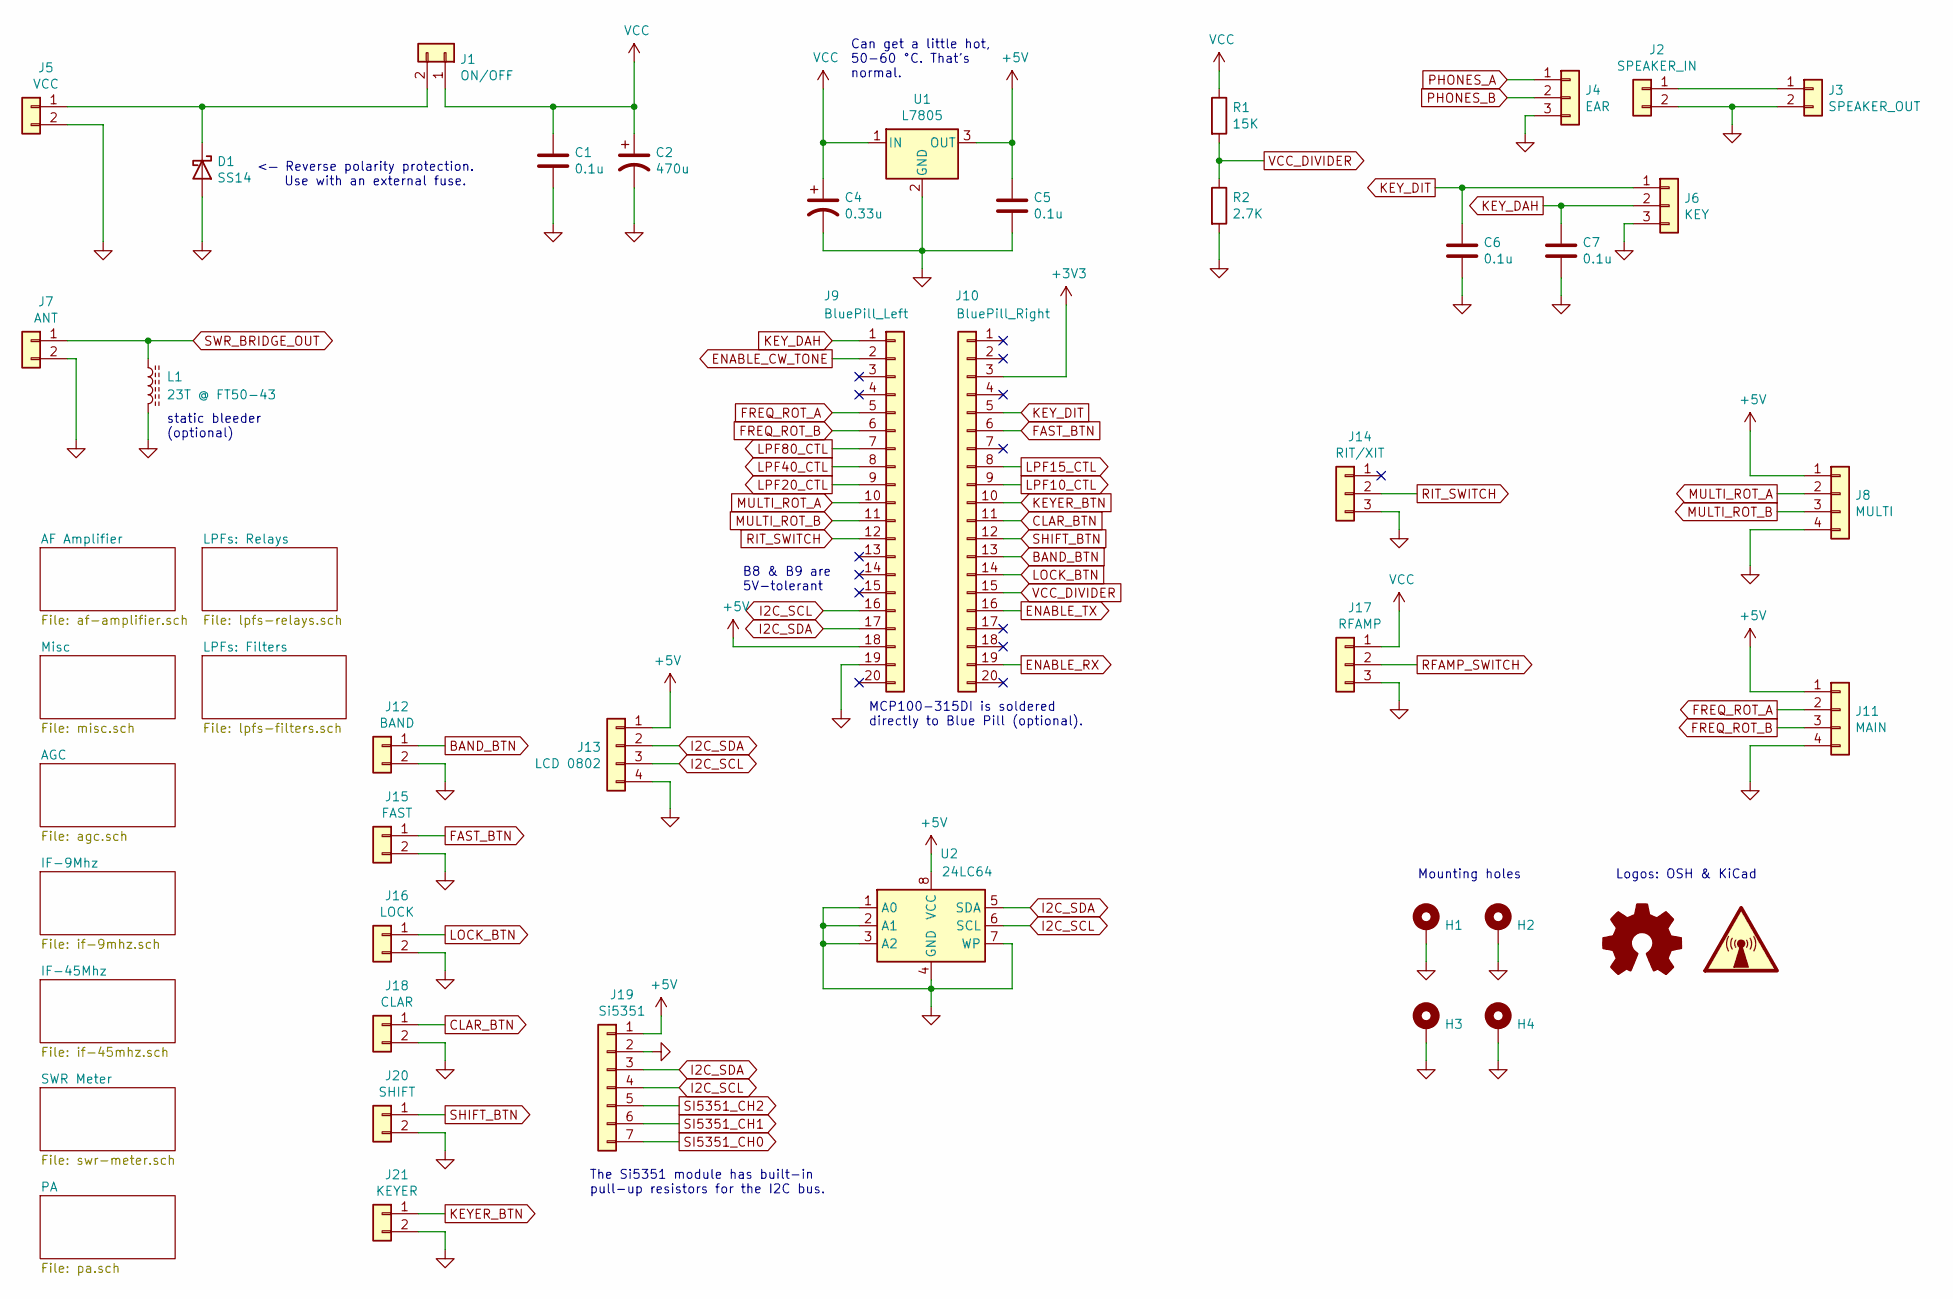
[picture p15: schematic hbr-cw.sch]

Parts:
C1, C5, C6, C7: 0.1u; C_0805_2012Metric_Pad1.15x1.40mm_HandSolder
C2: 470u; CP_Elec_10x10.5
C4: 0.33u; C_Radial_D5.0mm_H5.0mm_P2.00mm
D1: SS14; D_SMA_Handsoldering
H1, H2, H3, H4: MH; MountingHole_3.2mm_M3_Pad_Via
J1: ON/OFF; PinHeader_1x02_P2.54mm_Vertical
J2: SPEAKER_IN; PinHeader_1x02_P2.54mm_Vertical
J3: SPEAKER_OUT; PinHeader_1x02_P2.54mm_Vertical
J4: EAR; PinSocket_1x03_P2.54mm_Vertical
J5: VCC; PinHeader_1x02_P2.54mm_Vertical
J6: KEY; PinSocket_1x03_P2.54mm_Vertical
J7: ANT; PinHeader_1x02_P2.54mm_Vertical
J8: MULTI; PinHeader_1x04_P2.54mm_Vertical
J9: BluePill_Left; PinSocket_1x20_P2.54mm_Vertical
J10: BluePill_Right; PinSocket_1x20_P2.54mm_Vertical
J11: MAIN; PinHeader_1x04_P2.54mm_Vertical
J12: BAND; PinHeader_1x02_P2.54mm_Vertical
J13: LCD 0802; PinHeader_1x04_P2.54mm_Vertical
J14: RIT/XIT; PinSocket_1x03_P2.54mm_Vertical
J15: FAST; PinHeader_1x02_P2.54mm_Vertical
J16: LOCK; PinHeader_1x02_P2.54mm_Vertical
J17: RFAMP; PinSocket_1x03_P2.54mm_Vertical
J18: CLAR; PinHeader_1x02_P2.54mm_Vertical
J19: Si5351; PinHeader_1x07_P2.54mm_Vertical
J20: SHIFT; PinHeader_1x02_P2.54mm_Vertical
J21: KEYER; PinHeader_1x02_P2.54mm_Vertical
L1: 23T @ FT50-43; L_Toroid_Vertical_L13.0mm_W6.5mm_P5.60mm
R1: 15K; R_0805_2012Metric_Pad1.15x1.40mm_HandSolder
R2: 2.7K; R_0805_2012Metric_Pad1.15x1.40mm_HandSolder
SYM1: Logo_Open_Hardware_Small; OSHW-Logo2_9.8x8mm_SilkScreen
SYM2: SYM_Radio_Waves_Large; KiCad-Logo_5mm_SilkScreen
U1: L7805; TO-263-2
U2: 24LC64; SO-8_5.3x6.2mm_P1.27mm

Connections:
+3V3: J10.3
+5V: C5.1, J8.1, J9.18, J11.1, J13.1, J19.1, U1.3 (OUT), U2.8 (VCC); also elsewhere on the board
BAND_BTN: J10.13, J12.1
CLAR_BTN: J10.11, J18.1
ENABLE_CW_TONE: J9.2; also elsewhere on the board
ENABLE_RX: J10.19; also elsewhere on the board
ENABLE_TX: J10.16; also elsewhere on the board
FAST_BTN: J10.6, J15.1
FREQ_ROT_A: J9.5, J11.2
FREQ_ROT_B: J9.6, J11.3
GND: C1.2, C2.2, C4.2, C5.2, C6.2, C7.2, D1.2 (A), H1.1, H2.1, H3.1, H4.1, J2.2, J3.2, J4.3, J5.2, J6.3, J7.2, J8.4, J9.19, J11.4, J12.2, J13.4, J14.3, J15.2, J16.2, J17.3, J18.2, J19.2, J20.2, J21.2, L1.2, R2.2, U1.2 (GND), U2.1 (A0), U2.2 (A1), U2.3 (A2), U2.4 (GND), U2.7 (WP); also elsewhere on the board
I2C_SCL: J9.16, J13.3, J19.4, U2.6 (SCL); also elsewhere on the board
I2C_SDA: J9.17, J13.2, J19.3, U2.5 (SDA); also elsewhere on the board
KEYER_BTN: J10.10, J21.1
KEY_DAH: C7.1, J6.2, J9.1
KEY_DIT: C6.1, J6.1, J10.5
LOCK_BTN: J10.14, J16.1
LPF10_CTL: J10.9; also elsewhere on the board
LPF15_CTL: J10.8; also elsewhere on the board
LPF20_CTL: J9.9; also elsewhere on the board
LPF40_CTL: J9.8; also elsewhere on the board
LPF80_CTL: J9.7; also elsewhere on the board
MULTI_ROT_A: J8.2, J9.10
MULTI_ROT_B: J8.3, J9.11
unnamed: D1.1 (K), J1.2, J5.1
unnamed: J2.1, J3.1
PHONES_A: J4.1; also elsewhere on the board
PHONES_B: J4.2; also elsewhere on the board
RFAMP_SWITCH: J17.2; also elsewhere on the board
RIT_SWITCH: J9.12, J14.2
SHIFT_BTN: J10.12, J20.1
SI5351_CH0: J19.7; also elsewhere on the board
SI5351_CH1: J19.6; also elsewhere on the board
SI5351_CH2: J19.5; also elsewhere on the board
SWR_BRIDGE_OUT: J7.1, L1.1; also elsewhere on the board
VCC: C1.1, C2.1, C4.1, J1.1, J17.1, R1.1, U1.1 (IN); also elsewhere on the board
VCC_DIVIDER: J10.15, R1.2, R2.1

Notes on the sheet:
<— Reverse polarity protection. Use with an external fuse.
The Si5351 module has built-in pull-up resistors for the I2C bus.
static bleeder (optional)
B8 & B9 are 5V-tolerant
MCP100-315DI is soldered directly to Blue Pill (optional).
Mounting holes
Logos: OSH & KiCad
Can get a little hot, 50-60 °C. That’s normal.

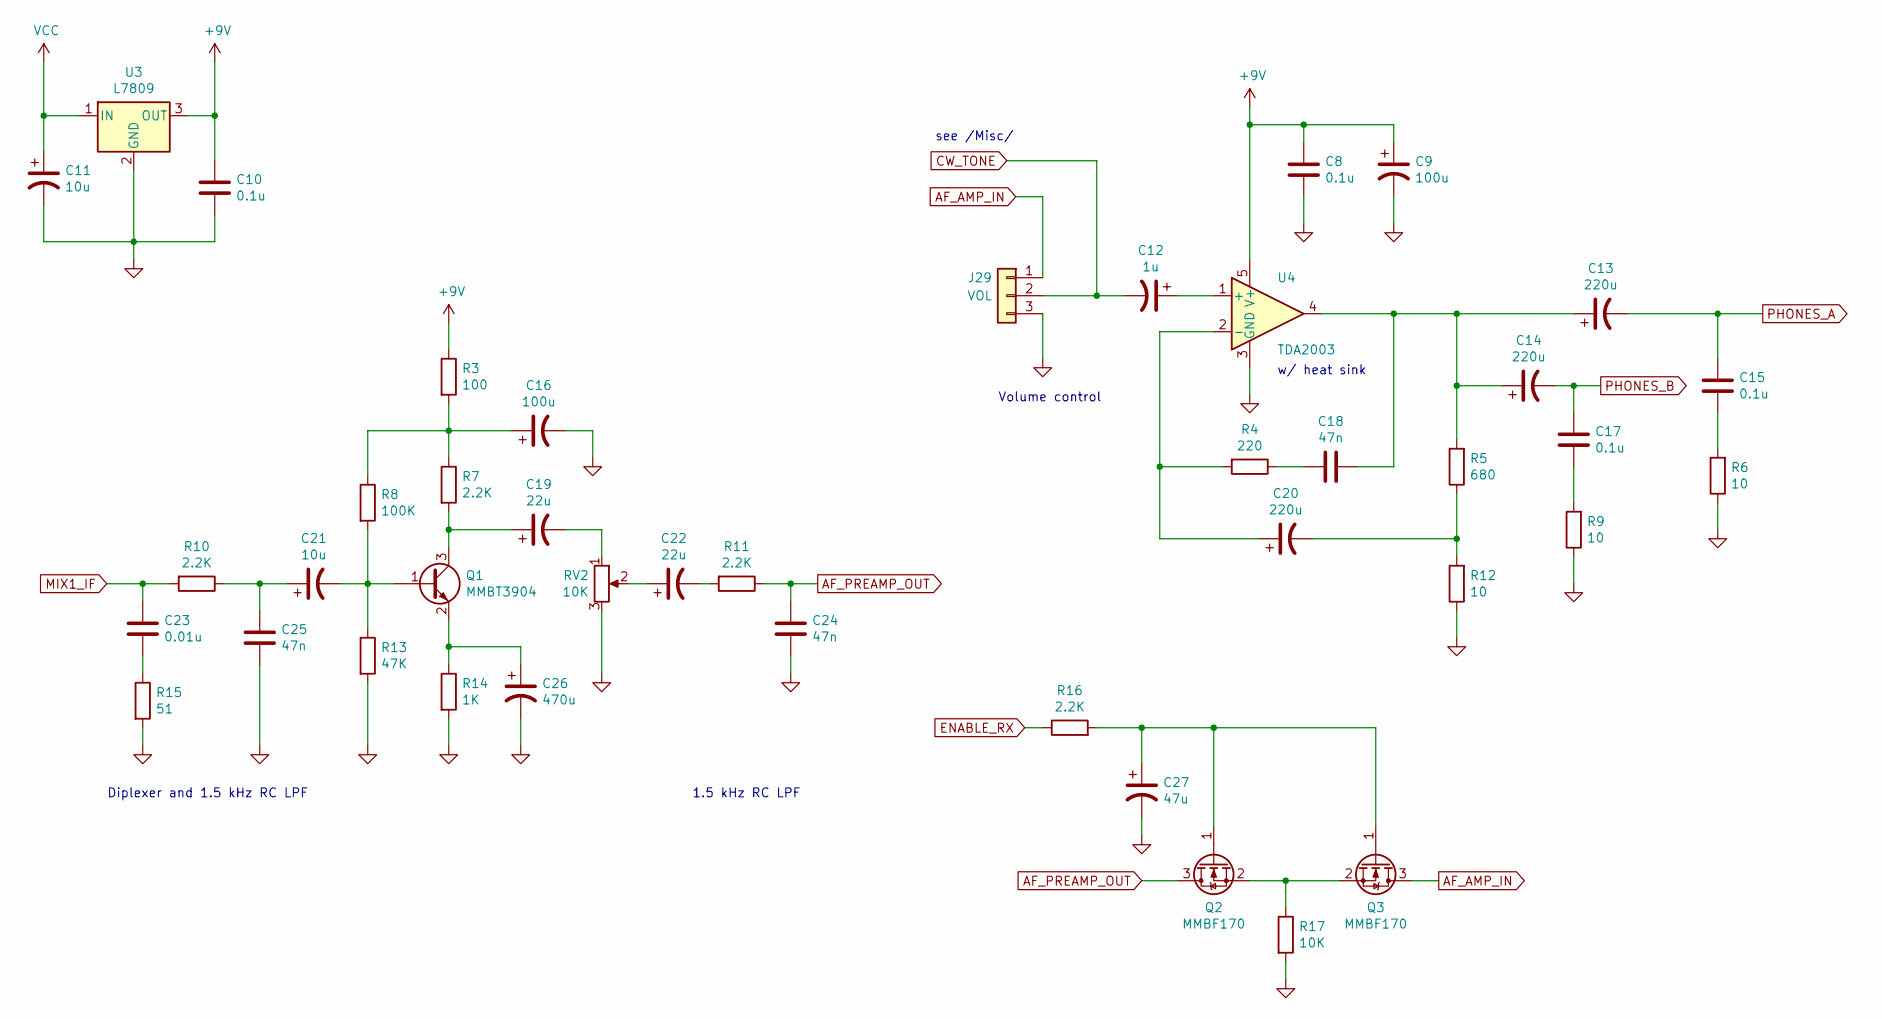
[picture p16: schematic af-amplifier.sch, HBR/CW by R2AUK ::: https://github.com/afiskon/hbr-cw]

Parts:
C8, C10, C15, C17: 0.1u; C_0805_2012Metric_Pad1.15x1.40mm_HandSolder
C9, C16: 100u; CP_Elec_6.3x7.7
C11, C21: 10u; CP_Elec_4x5.4
C12: 1u; CP_Elec_4x5.4
C13, C14, C20: 220u; CP_Elec_8x10.5
C18, C24, C25: 47n; C_0805_2012Metric_Pad1.15x1.40mm_HandSolder
C19, C22: 22u; CP_Elec_5x5.4
C23: 0.01u; C_0805_2012Metric_Pad1.15x1.40mm_HandSolder
C26: 470u; CP_Elec_10x10.5
C27: 47u; CP_Elec_6.3x5.8
J29: VOL; PinSocket_1x03_P2.54mm_Vertical
Q1: MMBT3904; SOT-23
Q2, Q3: MMBF170; SOT-23
R3: 100; R_0805_2012Metric_Pad1.15x1.40mm_HandSolder
R4: 220; R_0805_2012Metric_Pad1.15x1.40mm_HandSolder
R5: 680; R_0805_2012Metric_Pad1.15x1.40mm_HandSolder
R6, R9, R12: 10; R_0805_2012Metric_Pad1.15x1.40mm_HandSolder
R7, R10, R11, R16: 2.2K; R_0805_2012Metric_Pad1.15x1.40mm_HandSolder
R8: 100K; R_0805_2012Metric_Pad1.15x1.40mm_HandSolder
R13: 47K; R_0805_2012Metric_Pad1.15x1.40mm_HandSolder
R14: 1K; R_0805_2012Metric_Pad1.15x1.40mm_HandSolder
R15: 51; R_0805_2012Metric_Pad1.15x1.40mm_HandSolder
R17: 10K; R_0805_2012Metric_Pad1.15x1.40mm_HandSolder
RV2: 10K; Potentiometer_Bourns_3296W_Vertical
U3: L7809; TO-263-2
U4: TDA2003; TO-220-5_P3.4x3.7mm_StaggerOdd_Lead3.8mm_Vertical

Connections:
+9V: C8.1, C9.1, C10.1, R3.1, U3.3 (OUT), U4.5 (V+); also elsewhere on the board
AF_AMP_IN: J29.1, Q3.3 (D)
AF_PREAMP_OUT: C24.1, Q2.3 (D), R11.1
CW_TONE: C12.2, J29.2; also elsewhere on the board
ENABLE_RX: R16.1; also elsewhere on the board
GND: C8.2, C9.2, C10.2, C11.2, C16.2, C24.2, C25.2, C26.2, C27.2, J29.3, R6.1, R9.1, R12.1, R13.2, R14.2, R15.2, R17.2, RV2.3, U3.2 (GND), U4.3 (GND); also elsewhere on the board
MIX1_IF: C23.1, R10.2; also elsewhere on the board
unnamed: C12.1, U4.1 (+)
unnamed: C13.1, C14.1, C18.1, R5.2, U4.4
unnamed: C15.2, R6.2
unnamed: C16.1, R3.2, R7.1, R8.1
unnamed: C17.2, R9.2
unnamed: C18.2, R4.1
unnamed: C19.1, Q1.3 (C), R7.2
unnamed: C19.2, RV2.1
unnamed: C20.1, R4.2, U4.2 (-)
unnamed: C20.2, R5.1, R12.2
unnamed: C21.1, C25.1, R10.1
unnamed: C21.2, Q1.1 (B), R8.2, R13.1
unnamed: C22.1, RV2.2
unnamed: C22.2, R11.2
unnamed: C23.2, R15.1
unnamed: C26.1, Q1.2 (E), R14.1
unnamed: C27.1, Q2.1 (G), Q3.1 (G), R16.2
unnamed: Q2.2 (S), Q3.2 (S), R17.1
PHONES_A: C13.2, C15.1; also elsewhere on the board
PHONES_B: C14.2, C17.1; also elsewhere on the board
VCC: C11.1, U3.1 (IN); also elsewhere on the board

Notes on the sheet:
Volume control
w/ heat sink
see /Misc/
Diplexer and 1.5 kHz RC LPF
1.5 kHz RC LPF

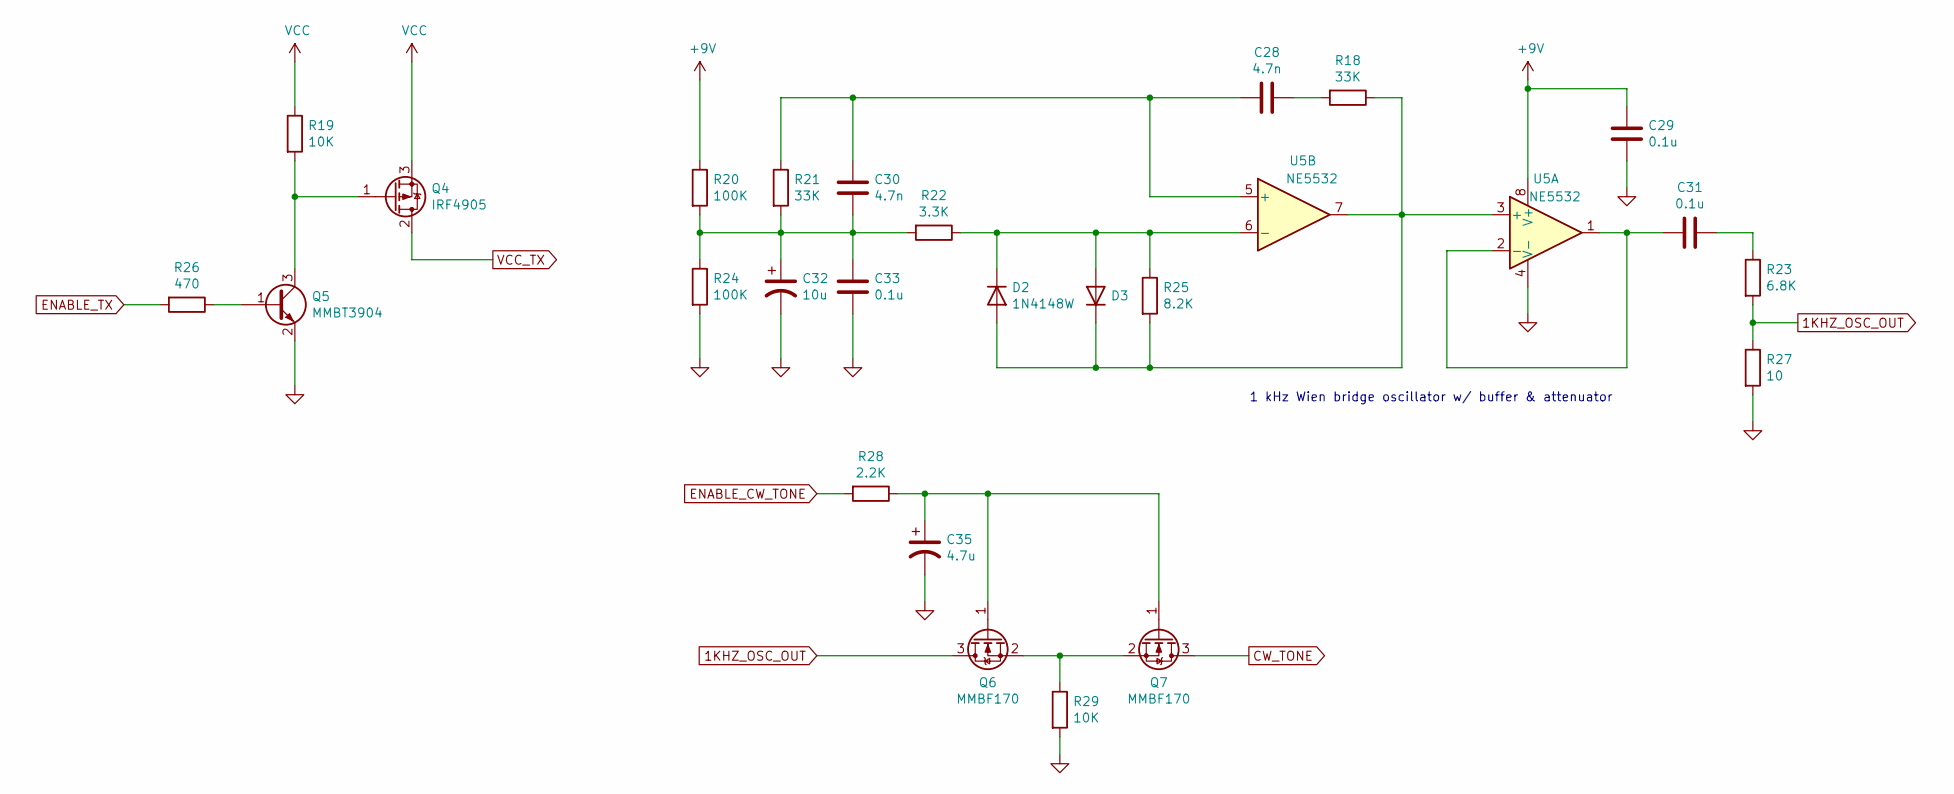
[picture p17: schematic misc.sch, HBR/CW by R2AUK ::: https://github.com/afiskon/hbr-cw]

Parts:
C28, C30: 4.7n; C_0805_2012Metric_Pad1.15x1.40mm_HandSolder
C29, C31, C33: 0.1u; C_0805_2012Metric_Pad1.15x1.40mm_HandSolder
C32: 10u; CP_Elec_4x5.4
C35: 4.7u; CP_Elec_4x5.4
D2, D3: 1N4148W; D_SOD-123
Q4: IRF4905; TO-220-3_Vertical
Q5: MMBT3904; SOT-23
Q6, Q7: MMBF170; SOT-23
R18, R21: 33K; R_0805_2012Metric_Pad1.15x1.40mm_HandSolder
R19, R29: 10K; R_0805_2012Metric_Pad1.15x1.40mm_HandSolder
R20, R24: 100K; R_0805_2012Metric_Pad1.15x1.40mm_HandSolder
R22: 3.3K; R_0805_2012Metric_Pad1.15x1.40mm_HandSolder
R23: 6.8K; R_0805_2012Metric_Pad1.15x1.40mm_HandSolder
R25: 8.2K; R_0805_2012Metric_Pad1.15x1.40mm_HandSolder
R26: 470; R_0805_2012Metric_Pad1.15x1.40mm_HandSolder
R27: 10; R_0805_2012Metric_Pad1.15x1.40mm_HandSolder
R28: 2.2K; R_0805_2012Metric_Pad1.15x1.40mm_HandSolder
U5: NE5532; SOIC-8_5.23x5.23mm_P1.27mm

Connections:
1KHZ_OSC_OUT: Q6.3 (D), R23.2, R27.1
+9V: C29.2, R20.1, U5.8 (V+); also elsewhere on the board
CW_TONE: Q7.3 (D); also elsewhere on the board
ENABLE_CW_TONE: R28.2; also elsewhere on the board
ENABLE_TX: R26.2; also elsewhere on the board
GND: C29.1, C32.2, C33.2, C35.2, Q5.2 (E), R24.2, R27.2, R29.2, U5.4 (V-); also elsewhere on the board
unnamed: C28.1, R18.2
unnamed: C28.2, C30.1, R21.1, U5.5 (+)
unnamed: C30.2, C32.1, C33.1, R20.2, R21.2, R22.2, R24.1
unnamed: C31.1, R23.1
unnamed: C31.2, U5.1, U5.2 (-)
unnamed: C35.1, Q6.1 (G), Q7.1 (G), R28.1
unnamed: D2.1 (K), D3.2 (A), R22.1, R25.1, U5.6 (-)
unnamed: D2.2 (A), D3.1 (K), R18.1, R25.2, U5.3 (+), U5.7
unnamed: Q4.1 (G), Q5.3 (C), R19.2
unnamed: Q5.1 (B), R26.1
unnamed: Q6.2 (S), Q7.2 (S), R29.1
VCC: Q4.3 (S), R19.1; also elsewhere on the board
VCC_TX: Q4.2 (D); also elsewhere on the board

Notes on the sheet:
1 kHz Wien bridge oscillator w/ buffer & attenuator

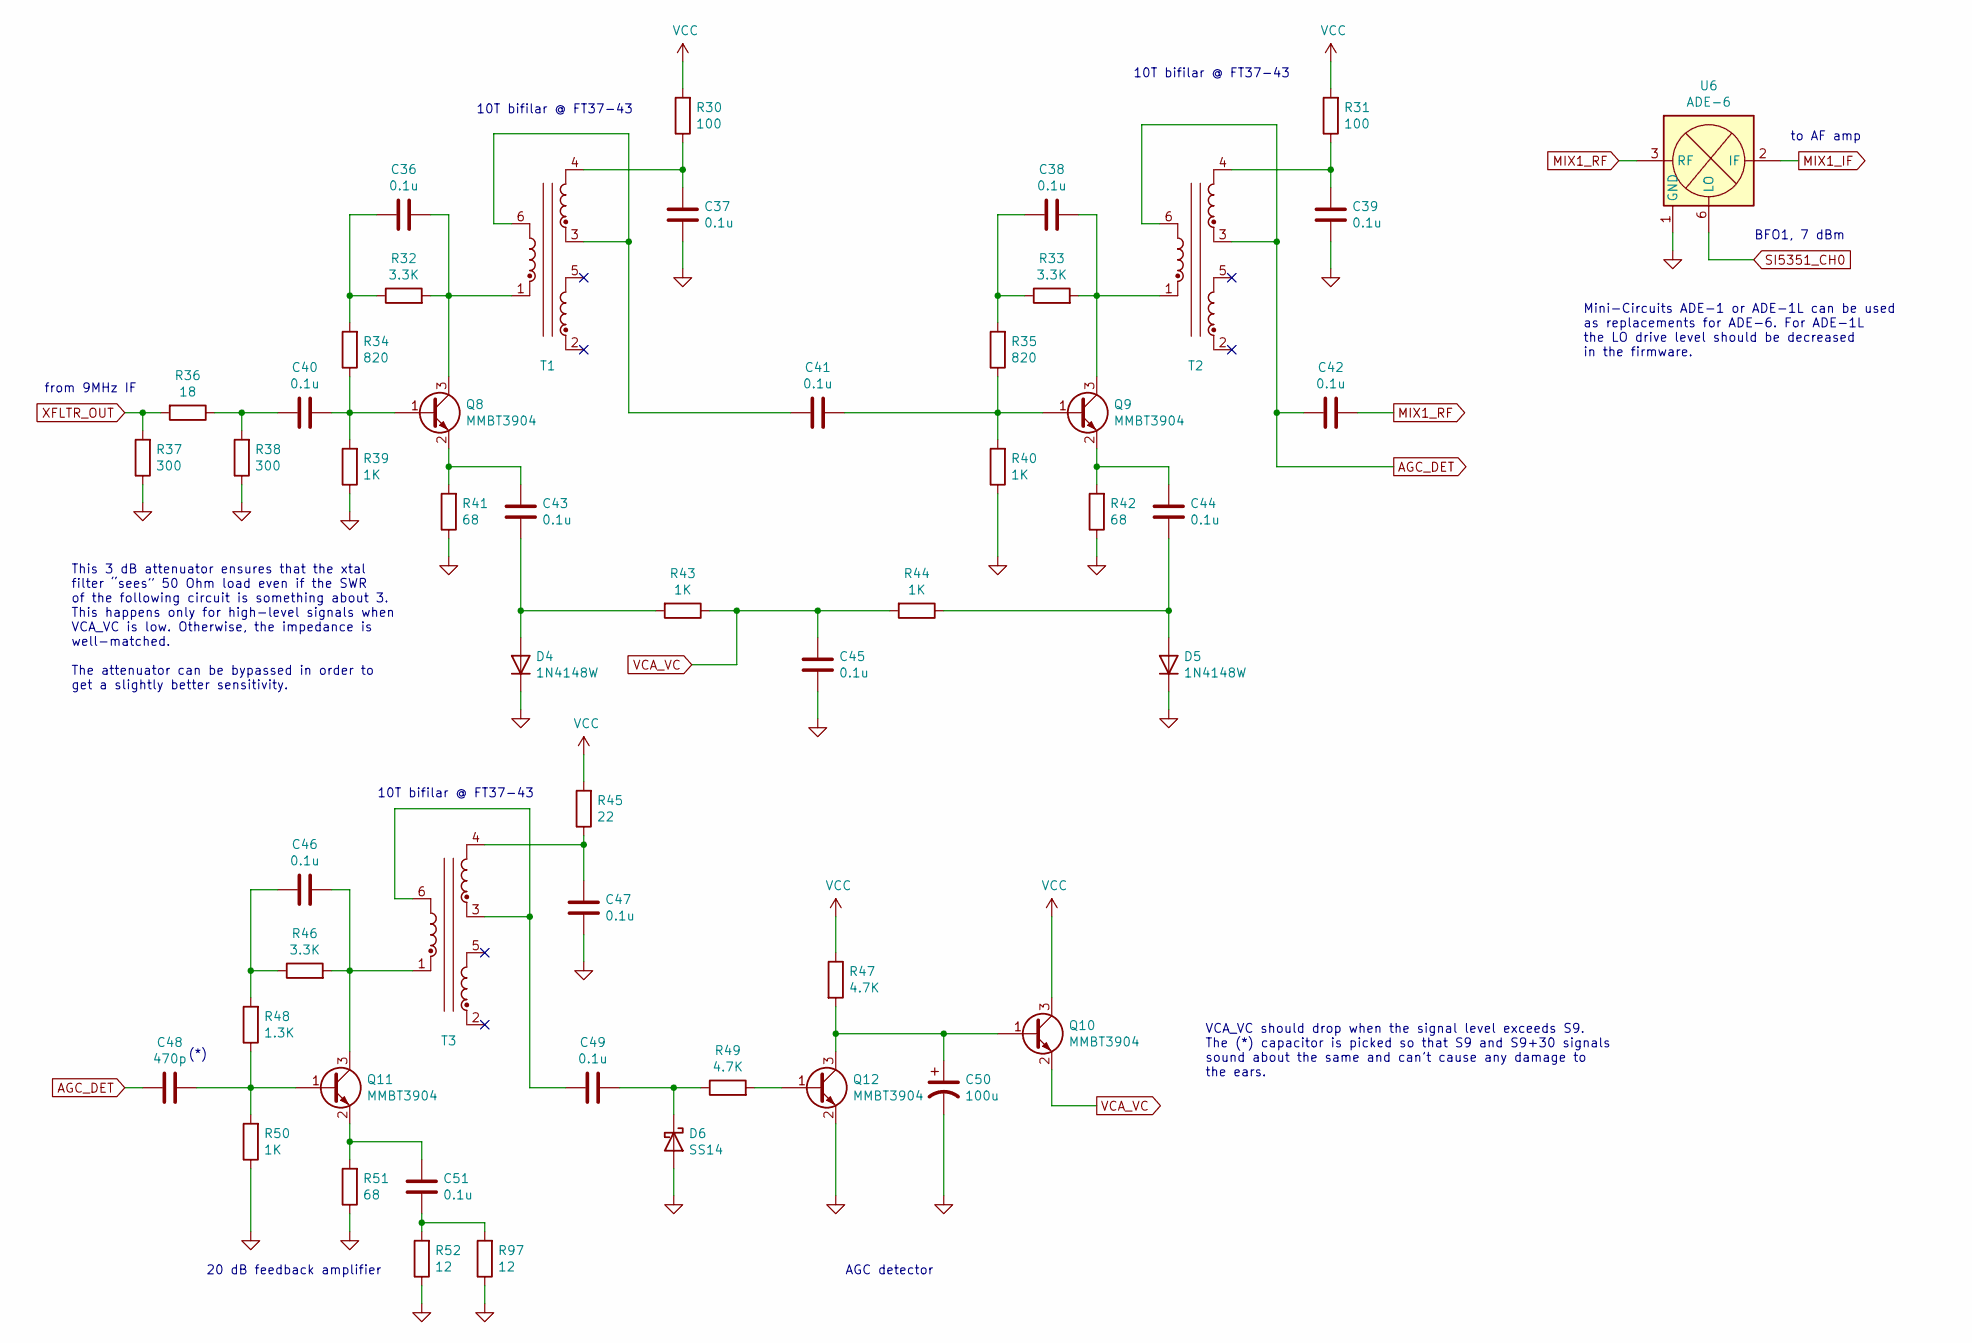
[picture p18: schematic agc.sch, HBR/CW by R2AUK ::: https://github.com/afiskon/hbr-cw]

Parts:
C36, C37, C38, C39, C40, C41, C42, C43, C44, C45, C46, C47, C49, C51: 0.1u; C_0805_2012Metric_Pad1.15x1.40mm_HandSolder
C48: 470p; C_0805_2012Metric_Pad1.15x1.40mm_HandSolder
C50: 100u; CP_Elec_6.3x7.7
D4, D5: 1N4148W; D_SOD-123
D6: SS14; D_SMA_Handsoldering
Q8, Q9, Q10, Q11, Q12: MMBT3904; SOT-23
R30, R31: 100; R_0805_2012Metric_Pad1.15x1.40mm_HandSolder
R32, R33, R46: 3.3K; R_0805_2012Metric_Pad1.15x1.40mm_HandSolder
R34, R35: 820; R_0805_2012Metric_Pad1.15x1.40mm_HandSolder
R36: 18; R_0805_2012Metric_Pad1.15x1.40mm_HandSolder
R37, R38: 300; R_0805_2012Metric_Pad1.15x1.40mm_HandSolder
R39, R40, R43, R44, R50: 1K; R_0805_2012Metric_Pad1.15x1.40mm_HandSolder
R41, R42, R51: 68; R_0805_2012Metric_Pad1.15x1.40mm_HandSolder
R45: 22; R_0805_2012Metric_Pad1.15x1.40mm_HandSolder
R47, R49: 4.7K; R_0805_2012Metric_Pad1.15x1.40mm_HandSolder
R48: 1.3K; R_0805_2012Metric_Pad1.15x1.40mm_HandSolder
R52, R97: 12; R_0805_2012Metric_Pad1.15x1.40mm_HandSolder
T1, T2, T3: FT37-43; DIP-6_W7.62mm
U6: ADE-6; Mini-Circuits_CD542_LandPatternPL-052

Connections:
AGC_DET: C42.2, C48.2, T2.3, T2.6
GND: C37.1, C39.1, C45.1, C47.1, C50.2, D4.1 (K), D5.1 (K), D6.2 (A), Q12.2 (E), R37.1, R38.1, R39.1, R40.1, R41.1, R42.1, R50.1, R51.1, R52.1, R97.1, U6.1 (GND), U6.4 (GND), U6.5 (GND); also elsewhere on the board
MIX1_IF: U6.2 (IF); also elsewhere on the board
MIX1_RF: C42.1, U6.3 (RF)
unnamed: C36.1, Q8.3 (C), R32.2, T1.1
unnamed: C36.2, R32.1, R34.2
unnamed: C37.2, R30.1, T1.4
unnamed: C38.1, Q9.3 (C), R33.2, T2.1
unnamed: C38.2, R33.1, R35.2
unnamed: C39.2, R31.1, T2.4
unnamed: C40.1, Q8.1 (B), R34.1, R39.2
unnamed: C40.2, R36.1, R38.2
unnamed: C41.1, Q9.1 (B), R35.1, R40.2
unnamed: C41.2, T1.3, T1.6
unnamed: C43.1, D4.2 (A), R43.2
unnamed: C43.2, Q8.2 (E), R41.2
unnamed: C44.1, D5.2 (A), R44.1
unnamed: C44.2, Q9.2 (E), R42.2
unnamed: C46.1, Q11.3 (C), R46.2, T3.1
unnamed: C46.2, R46.1, R48.2
unnamed: C47.2, R45.1, T3.4
unnamed: C48.1, Q11.1 (B), R48.1, R50.2
unnamed: C49.1, D6.1 (K), R49.1
unnamed: C49.2, T3.3, T3.6
unnamed: C50.1, Q10.1 (B), Q12.3 (C), R47.2
unnamed: C51.1, R52.2, R97.2
unnamed: C51.2, Q11.2 (E), R51.2
unnamed: Q12.1 (B), R49.2
SI5351_CH0: U6.6 (LO); also elsewhere on the board
VCA_VC: C45.2, Q10.2 (E), R43.1, R44.2
VCC: Q10.3 (C), R30.2, R31.2, R45.2, R47.1; also elsewhere on the board
XFLTR_OUT: R36.2, R37.2; also elsewhere on the board

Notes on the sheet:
10T bifilar @ FT37-43
BFO1, 7 dBm
20 dB feedback amplifier
VCA_VC should drop when the signal level exceeds S9. The (*) capacitor is picked so that S9 and S9+30 signals sound about the same and can’t cause any damage to the ears.
AGC detector
(*)
This 3 dB attenuator ensures that the xtal filter “sees” 50 Ohm load even if the SWR of the following circuit is something about 3. This happens only for high-level signals when VCA_VC is low. Otherwise, the impedance is well-matched. The attenuator can be bypassed in order to get a slightly better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
from 9MHz IF
to AF amp
Mini-Circuits ADE-1 or ADE-1L can be used as replacements for ADE-6. For ADE-1L the LO drive level should be decreased in the firmware.

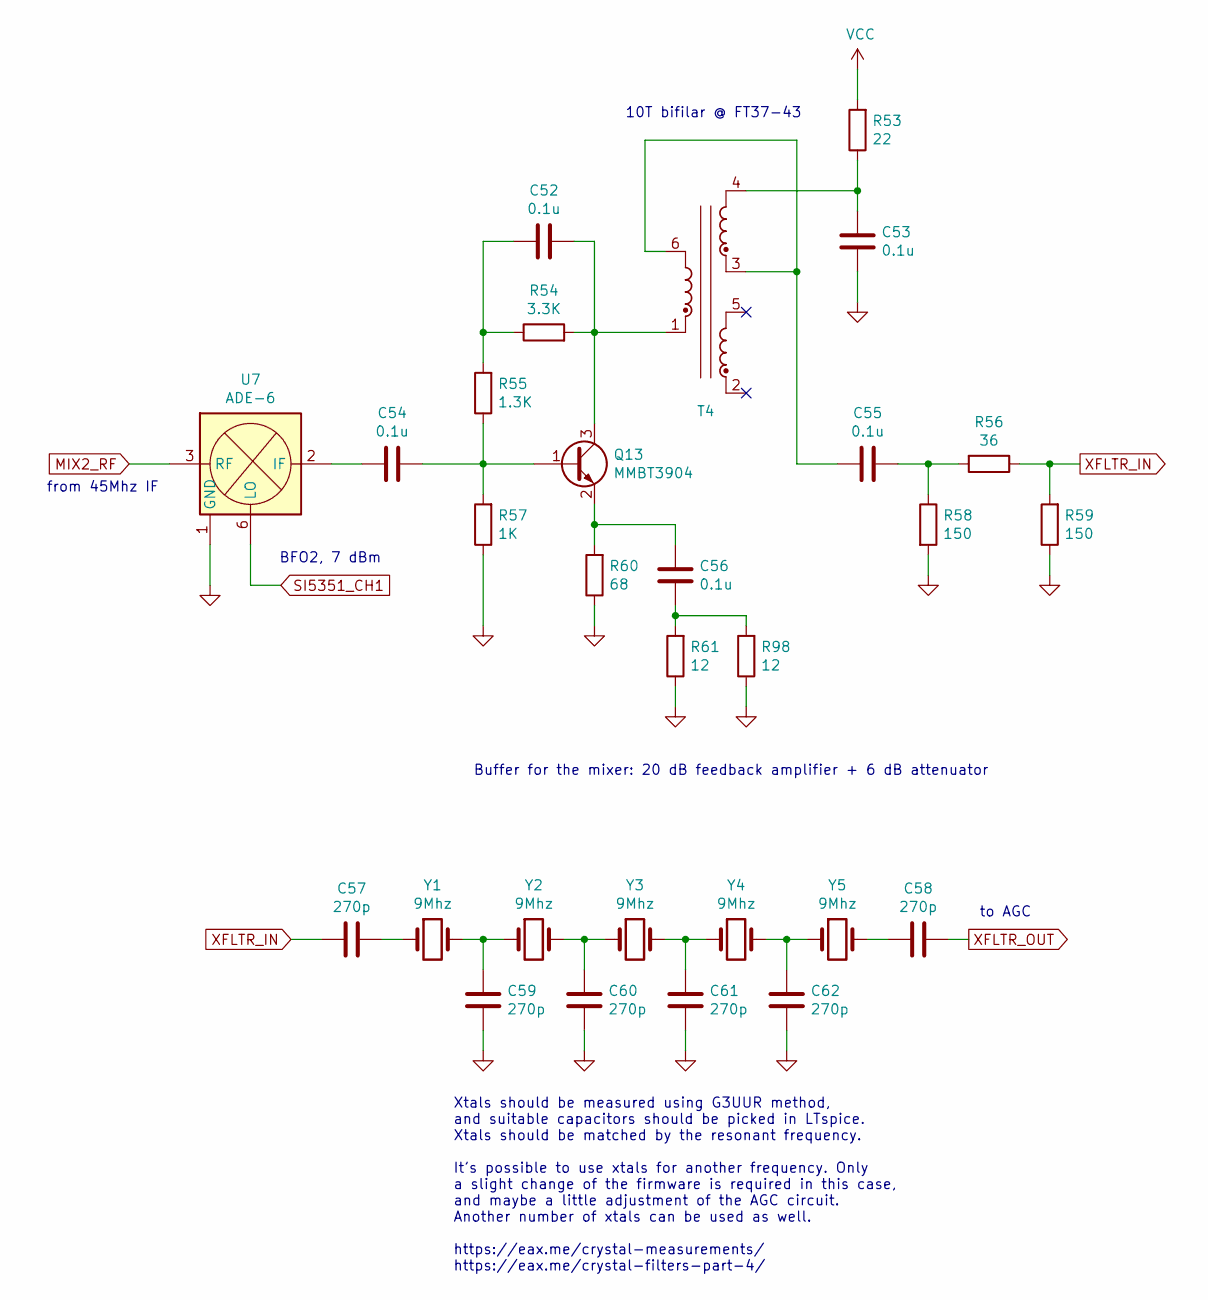
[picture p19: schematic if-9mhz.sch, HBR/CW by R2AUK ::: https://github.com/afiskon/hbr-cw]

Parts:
C52, C53, C54, C55, C56: 0.1u; C_0805_2012Metric_Pad1.15x1.40mm_HandSolder
C57, C58, C59, C60, C61, C62: 270p; C_0805_2012Metric_Pad1.15x1.40mm_HandSolder
Q13: MMBT3904; SOT-23
R53: 22; R_0805_2012Metric_Pad1.15x1.40mm_HandSolder
R54: 3.3K; R_0805_2012Metric_Pad1.15x1.40mm_HandSolder
R55: 1.3K; R_0805_2012Metric_Pad1.15x1.40mm_HandSolder
R56: 36; R_0805_2012Metric_Pad1.15x1.40mm_HandSolder
R57: 1K; R_0805_2012Metric_Pad1.15x1.40mm_HandSolder
R58, R59: 150; R_0805_2012Metric_Pad1.15x1.40mm_HandSolder
R60: 68; R_0805_2012Metric_Pad1.15x1.40mm_HandSolder
R61, R98: 12; R_0805_2012Metric_Pad1.15x1.40mm_HandSolder
T4: FT37-43; DIP-6_W7.62mm
U7: ADE-6; Mini-Circuits_CD542_LandPatternPL-052
Y1, Y2, Y3, Y4, Y5: 9Mhz; Crystal_HC49-U_Vertical

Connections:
GND: C53.1, C59.2, C60.2, C61.2, C62.2, R57.1, R58.2, R59.1, R60.1, R61.1, R98.1, U7.1 (GND), U7.4 (GND), U7.5 (GND); also elsewhere on the board
MIX2_RF: U7.3 (RF); also elsewhere on the board
unnamed: C52.1, Q13.3 (C), R54.2, T4.1
unnamed: C52.2, R54.1, R55.2
unnamed: C53.2, R53.1, T4.4
unnamed: C54.1, Q13.1 (B), R55.1, R57.2
unnamed: C54.2, U7.2 (IF)
unnamed: C55.1, R56.2, R58.1
unnamed: C55.2, T4.3, T4.6
unnamed: C56.1, R61.2, R98.2
unnamed: C56.2, Q13.2 (E), R60.2
unnamed: C57.1, Y1.1
unnamed: C58.2, Y5.2
unnamed: C59.1, Y1.2, Y2.1
unnamed: C60.1, Y2.2, Y3.1
unnamed: C61.1, Y3.2, Y4.1
unnamed: C62.1, Y4.2, Y5.1
SI5351_CH1: U7.6 (LO); also elsewhere on the board
VCC: R53.2; also elsewhere on the board
XFLTR_IN: C57.2, R56.1, R59.2
XFLTR_OUT: C58.1; also elsewhere on the board

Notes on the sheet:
10T bifilar @ FT37-43
Buffer for the mixer: 20 dB feedback amplifier + 6 dB attenuator
BFO2, 7 dBm
from 45Mhz IF
to AGC
Xtals should be measured using G3UUR method, and suitable capacitors should be picked in LTspice. Xtals should be matched by the resonant frequency. It’s possible to use xtals for another frequency. Only a slight change of the firmware is required in this case, and maybe a little adjustment of the 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

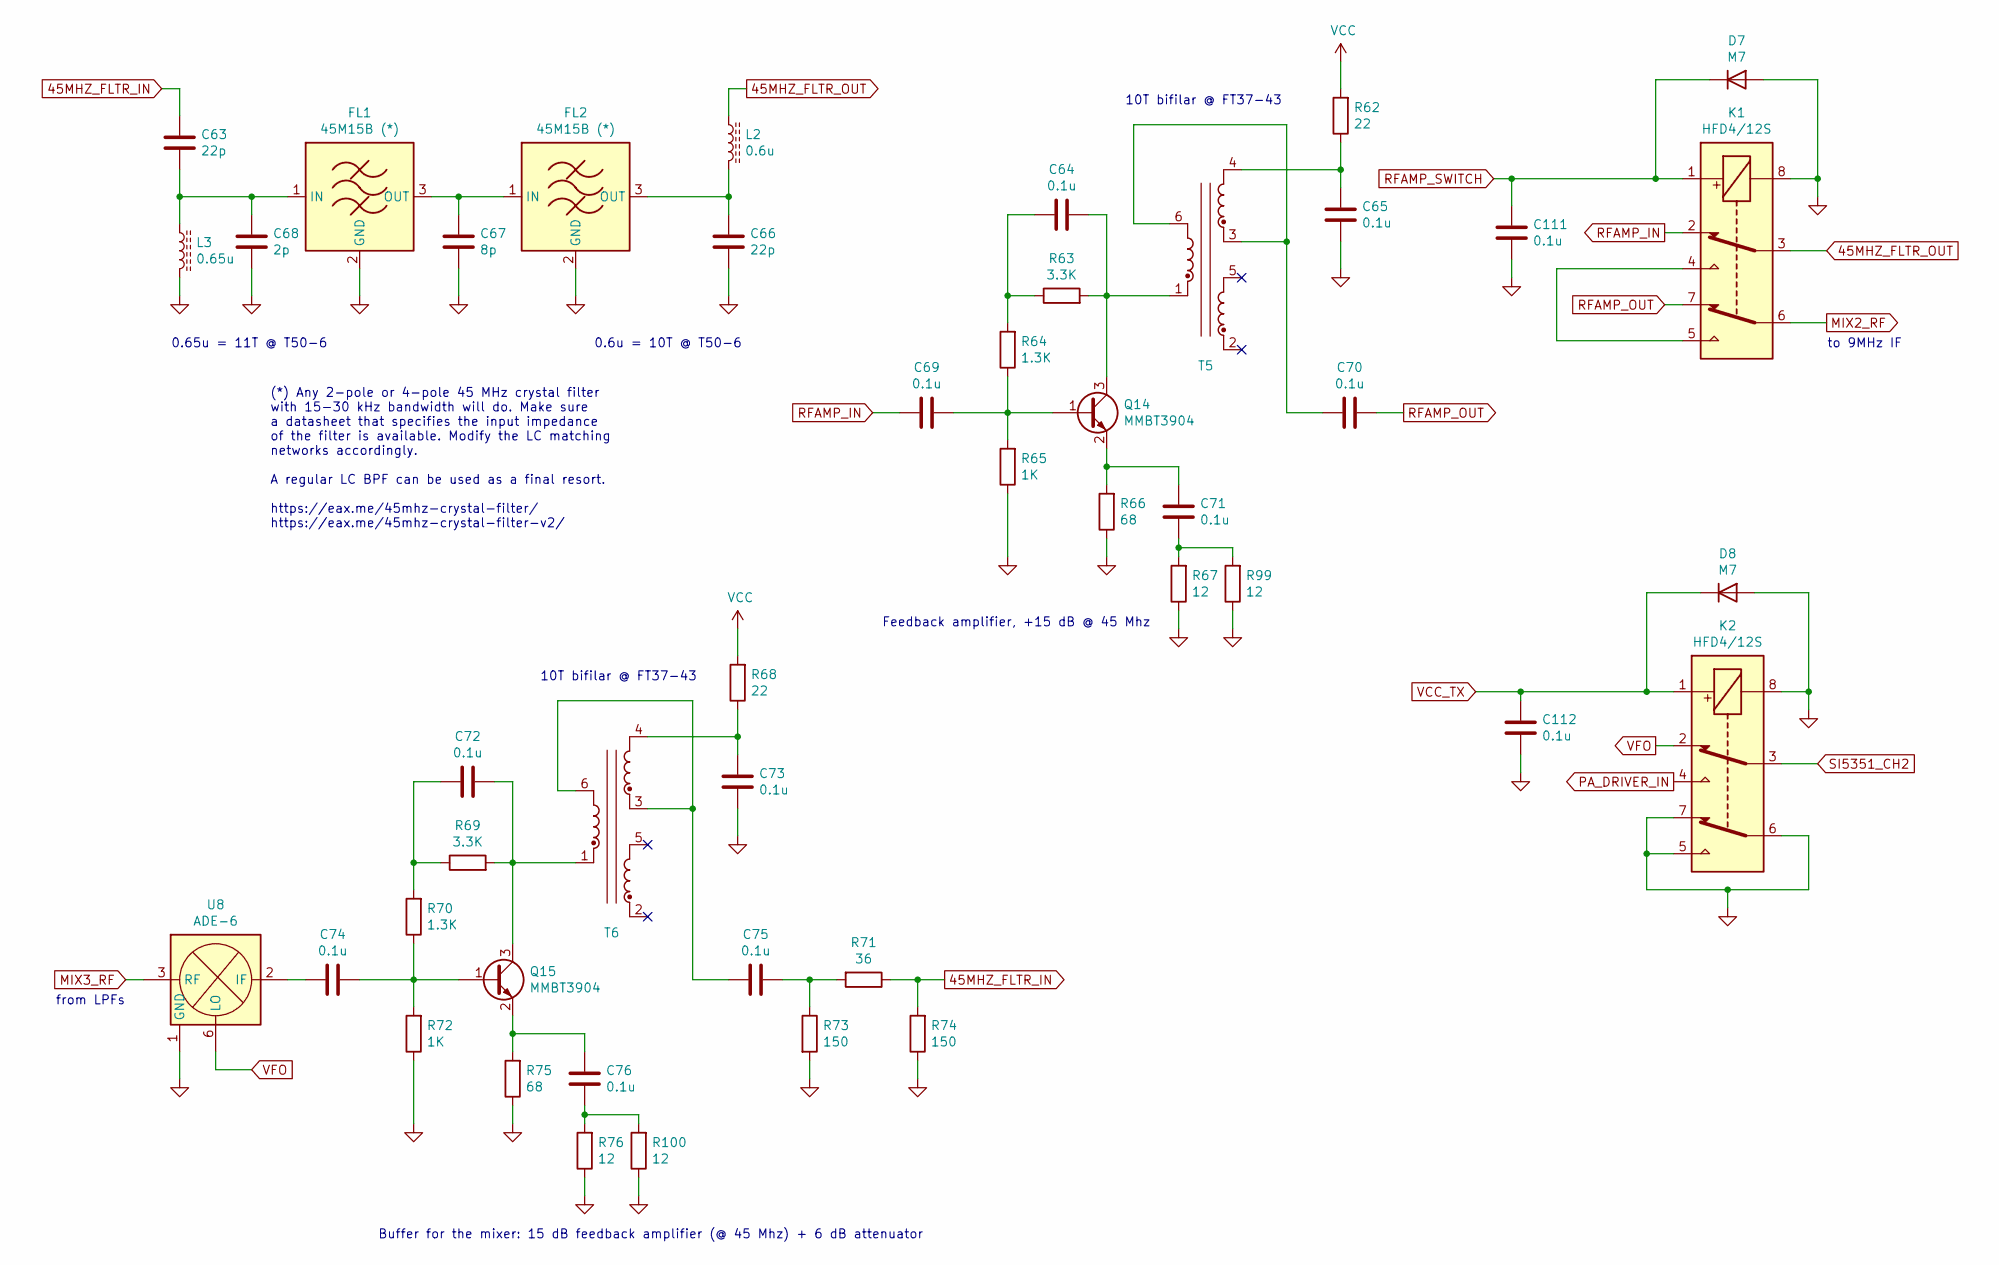
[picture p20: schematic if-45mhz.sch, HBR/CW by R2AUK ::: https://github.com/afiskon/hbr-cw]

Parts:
C63, C66: 22p; C_0805_2012Metric_Pad1.15x1.40mm_HandSolder
C64, C65, C69, C70, C71, C72, C73, C74, C75, C76, C111, C112: 0.1u; C_0805_2012Metric_Pad1.15x1.40mm_HandSolder
C67: 8p; C_0805_2012Metric_Pad1.15x1.40mm_HandSolder
C68: 2p; C_0805_2012Metric_Pad1.15x1.40mm_HandSolder
D7, D8: M7; D_SMA_Handsoldering
FL1, FL2: 45M15B (*); Resonator-3Pin_W7.0mm_H2.5mm
K1, K2: HFD4/12S; Relay_DPDT_Omron_G6K-2F-Y
L2: 0.6u; L_Toroid_Vertical_L13.0mm_W6.5mm_P5.60mm
L3: 0.65u; L_Toroid_Vertical_L13.0mm_W6.5mm_P5.60mm
Q14, Q15: MMBT3904; SOT-23
R62, R68: 22; R_0805_2012Metric_Pad1.15x1.40mm_HandSolder
R63, R69: 3.3K; R_0805_2012Metric_Pad1.15x1.40mm_HandSolder
R64, R70: 1.3K; R_0805_2012Metric_Pad1.15x1.40mm_HandSolder
R65, R72: 1K; R_0805_2012Metric_Pad1.15x1.40mm_HandSolder
R66, R75: 68; R_0805_2012Metric_Pad1.15x1.40mm_HandSolder
R67, R76, R99, R100: 12; R_0805_2012Metric_Pad1.15x1.40mm_HandSolder
R71: 36; R_0805_2012Metric_Pad1.15x1.40mm_HandSolder
R73, R74: 150; R_0805_2012Metric_Pad1.15x1.40mm_HandSolder
T5, T6: FT37-43; DIP-6_W7.62mm
U8: ADE-6; Mini-Circuits_CD542_LandPatternPL-052

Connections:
45MHZ_FLTR_IN: C63.1, R71.1, R74.2
45MHZ_FLTR_OUT: K1.3, L2.1
GND: C65.1, C66.1, C67.1, C68.1, C73.1, C111.2, C112.2, D7.2 (A), D8.2 (A), FL1.2 (GND), FL2.2 (GND), K1.8, K2.5, K2.6, K2.7, K2.8, L3.2, R65.1, R66.1, R67.1, R72.1, R73.2, R74.1, R75.1, R76.1, R99.1, R100.1, U8.1 (GND), U8.4 (GND), U8.5 (GND); also elsewhere on the board
MIX2_RF: K1.6; also elsewhere on the board
MIX3_RF: U8.3 (RF); also elsewhere on the board
unnamed: C63.2, C68.2, FL1.1 (IN), L3.1
unnamed: C64.1, Q14.3 (C), R63.2, T5.1
unnamed: C64.2, R63.1, R64.2
unnamed: C65.2, R62.1, T5.4
unnamed: C66.2, FL2.3 (OUT), L2.2
unnamed: C67.2, FL1.3 (OUT), FL2.1 (IN)
unnamed: C69.1, Q14.1 (B), R64.1, R65.2
unnamed: C70.2, T5.3, T5.6
unnamed: C71.1, R67.2, R99.2
unnamed: C71.2, Q14.2 (E), R66.2
unnamed: C72.1, Q15.3 (C), R69.2, T6.1
unnamed: C72.2, R69.1, R70.2
unnamed: C73.2, R68.1, T6.4
unnamed: C74.1, Q15.1 (B), R70.1, R72.2
unnamed: C74.2, U8.2 (IF)
unnamed: C75.1, R71.2, R73.1
unnamed: C75.2, T6.3, T6.6
unnamed: C76.1, R76.2, R100.2
unnamed: C76.2, Q15.2 (E), R75.2
unnamed: K1.4, K1.5
PA_DRIVER_IN: K2.4; also elsewhere on the board
RFAMP_IN: C69.2, K1.2
RFAMP_OUT: C70.1, K1.7
RFAMP_SWITCH: C111.1, D7.1 (K), K1.1; also elsewhere on the board
SI5351_CH2: K2.3; also elsewhere on the board
VCC: R62.2, R68.2; also elsewhere on the board
VCC_TX: C112.1, D8.1 (K), K2.1; also elsewhere on the board
VFO: K2.2, U8.6 (LO)

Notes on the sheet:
10T bifilar @ FT37-43
Feedback amplifier, +15 dB @ 45 Mhz
Buffer for the mixer: 15 dB feedback amplifier (@ 45 Mhz) + 6 dB attenuator
to 9MHz IF
from LPFs
0.6u = 10T @ T50-6
0.65u = 11T @ T50-6
(*) Any 2-pole or 4-pole 45 MHz crystal filter with 15-30 kHz bandwidth will do. Make sure a datasheet that specifies the input impedance of the filter is available. Modify the LC matching networks accordingly. A regular LC BPF can be used as a final resort. https://eax.me/45mhz-crystal-filter/ htt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

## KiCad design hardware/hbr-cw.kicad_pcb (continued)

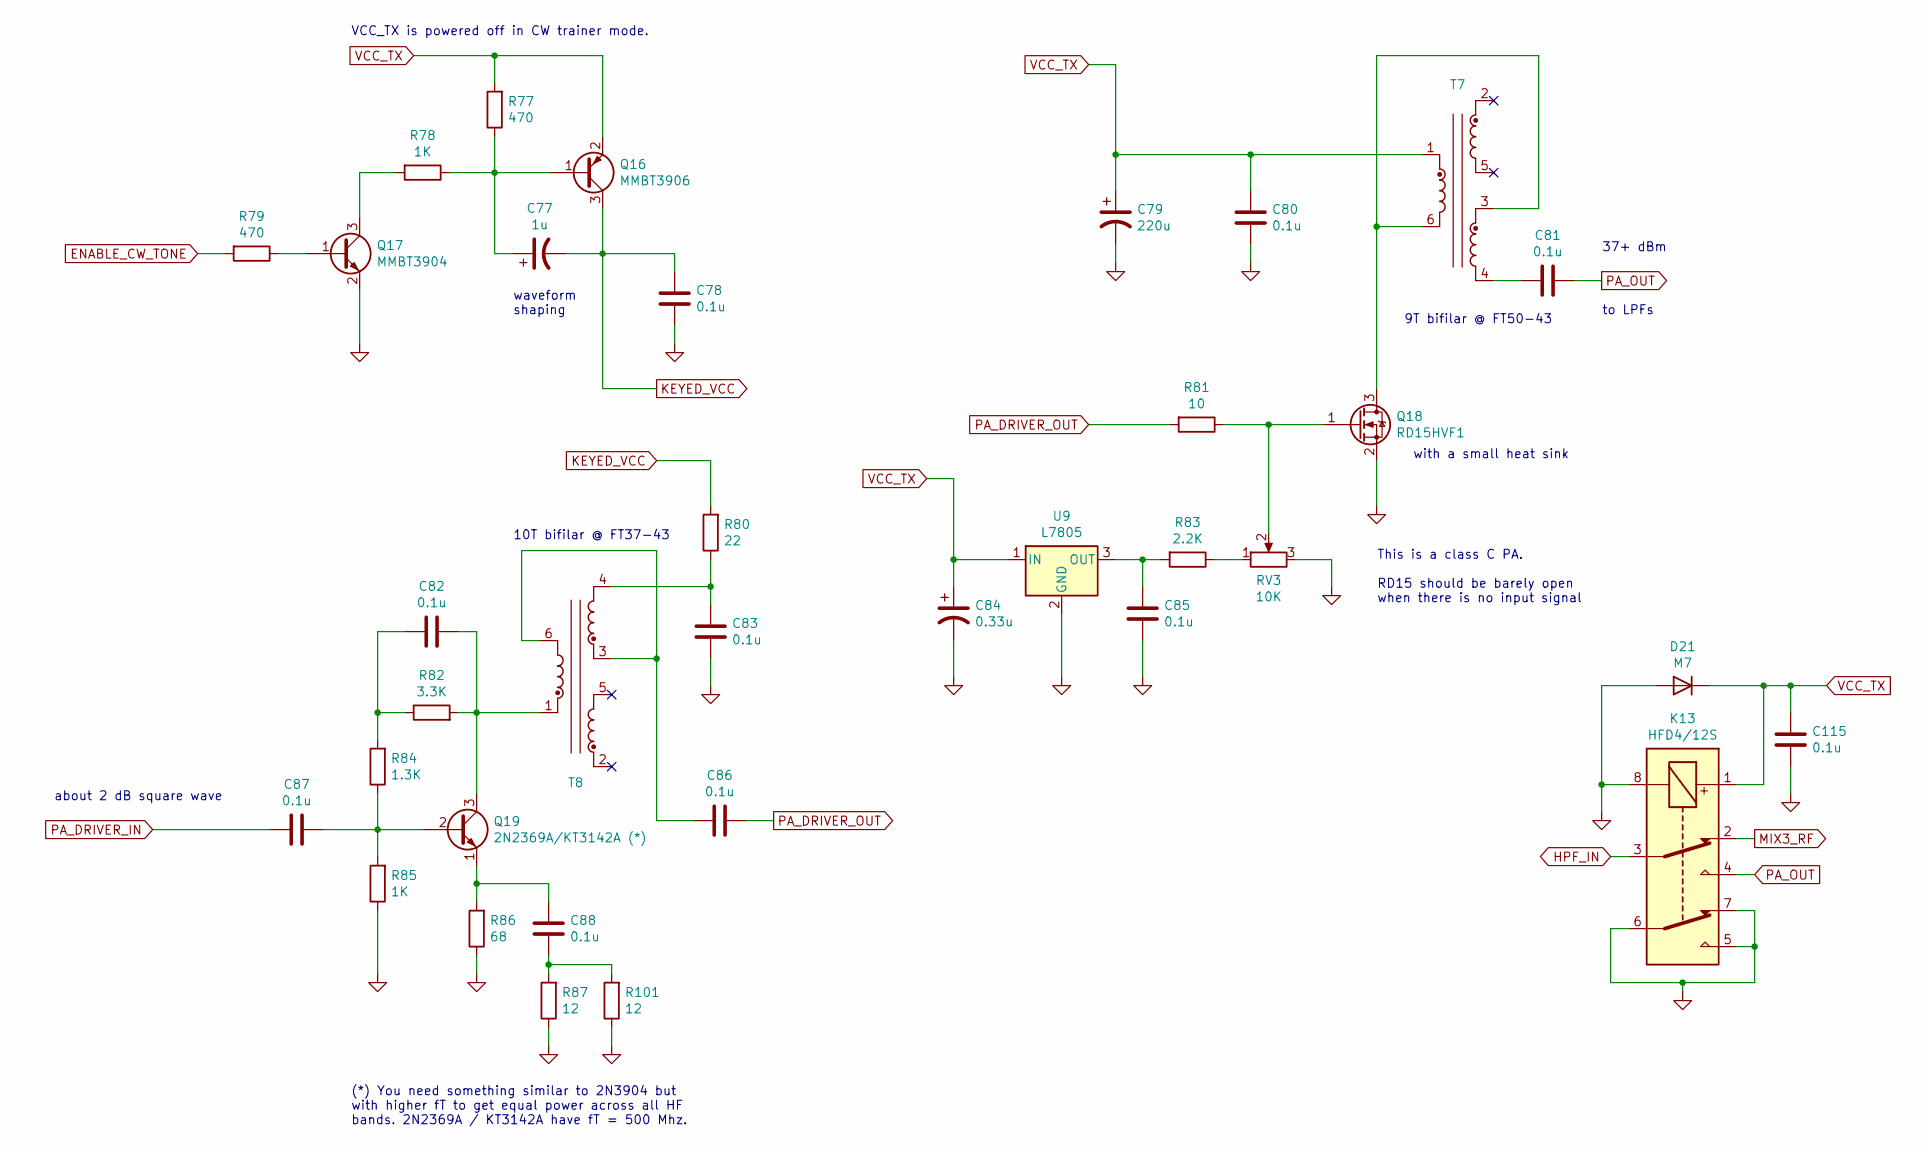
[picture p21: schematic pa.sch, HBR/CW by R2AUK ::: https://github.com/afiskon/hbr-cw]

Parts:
C77: 1u; CP_Elec_4x5.4
C78, C80, C81, C82, C83, C85, C86, C87, C88, C115: 0.1u; C_0805_2012Metric_Pad1.15x1.40mm_HandSolder
C79: 220u; CP_Elec_8x10.5
C84: 0.33u; C_Radial_D5.0mm_H5.0mm_P2.00mm
D21: M7; D_SMA_Handsoldering
K13: HFD4/12S; Relay_DPDT_Omron_G6K-2F-Y
Q16: MMBT3906; SOT-23
Q17: MMBT3904; SOT-23
Q18: RD15HVF1; TO-220-3_Vertical
Q19: 2N2369A/КТ3142A (*); TO-18-3
R77, R79: 470; R_0805_2012Metric_Pad1.15x1.40mm_HandSolder
R78, R85: 1K; R_0805_2012Metric_Pad1.15x1.40mm_HandSolder
R80: 22; R_0805_2012Metric_Pad1.15x1.40mm_HandSolder
R81: 10; R_0805_2012Metric_Pad1.15x1.40mm_HandSolder
R82: 3.3K; R_0805_2012Metric_Pad1.15x1.40mm_HandSolder
R83: 2.2K; R_0805_2012Metric_Pad1.15x1.40mm_HandSolder
R84: 1.3K; R_0805_2012Metric_Pad1.15x1.40mm_HandSolder
R86: 68; R_0805_2012Metric_Pad1.15x1.40mm_HandSolder
R87, R101: 12; R_0805_2012Metric_Pad1.15x1.40mm_HandSolder
RV3: 10K; Potentiometer_Bourns_3296W_Vertical
T7: FT50-43; DIP-6_W7.62mm
T8: FT37-43; DIP-6_W7.62mm
U9: L7805; TO-263-2

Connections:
ENABLE_CW_TONE: R79.2; also elsewhere on the board
GND: C78.1, C79.2, C80.2, C83.1, C84.2, C85.2, C115.2, D21.2 (A), K13.5, K13.6, K13.7, K13.8, Q17.2 (E), Q18.2 (S), R85.1, R86.1, R87.1, R101.1, RV3.3, U9.2 (GND); also elsewhere on the board
HPF_IN: K13.3; also elsewhere on the board
KEYED_VCC: C77.2, C78.2, Q16.3 (C), R80.2
MIX3_RF: K13.2; also elsewhere on the board
unnamed: C77.1, Q16.1 (B), R77.1, R78.1
unnamed: C81.2, T7.4
unnamed: C82.1, Q19.3 (C), R82.2, T8.1
unnamed: C82.2, R82.1, R84.2
unnamed: C83.2, R80.1, T8.4
unnamed: C85.1, R83.2, U9.3 (OUT)
unnamed: C86.2, T8.3, T8.6
unnamed: C87.1, Q19.2 (B), R84.1, R85.2
unnamed: C88.1, R87.2, R101.2
unnamed: C88.2, Q19.1 (E), R86.2
unnamed: Q17.1 (B), R79.1
unnamed: Q17.3 (C), R78.2
unnamed: Q18.1 (G), R81.1, RV3.2
unnamed: Q18.3 (D), T7.3, T7.6
unnamed: R83.1, RV3.1
PA_DRIVER_IN: C87.2; also elsewhere on the board
PA_DRIVER_OUT: C86.1, R81.2
PA_OUT: C81.1, K13.4
VCC_TX: C79.1, C80.1, C84.1, C115.1, D21.1 (K), K13.1, Q16.2 (E), R77.2, T7.1, U9.1 (IN); also elsewhere on the board

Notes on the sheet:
about 2 dB square wave
10T bifilar @ FT37-43
(*) You need something similar to 2N3904 but with higher fT to get equal power across all HF bands. 2N2369A / KT3142A have fT = 500 Mhz.
waveform shaping
with a small heat sink
9T bifilar @ FT50-43
to LPFs
This is a class C PA. RD15 should be barely open when there is no input signal
37+ dBm
VCC_TX is powered off in CW trainer mode.

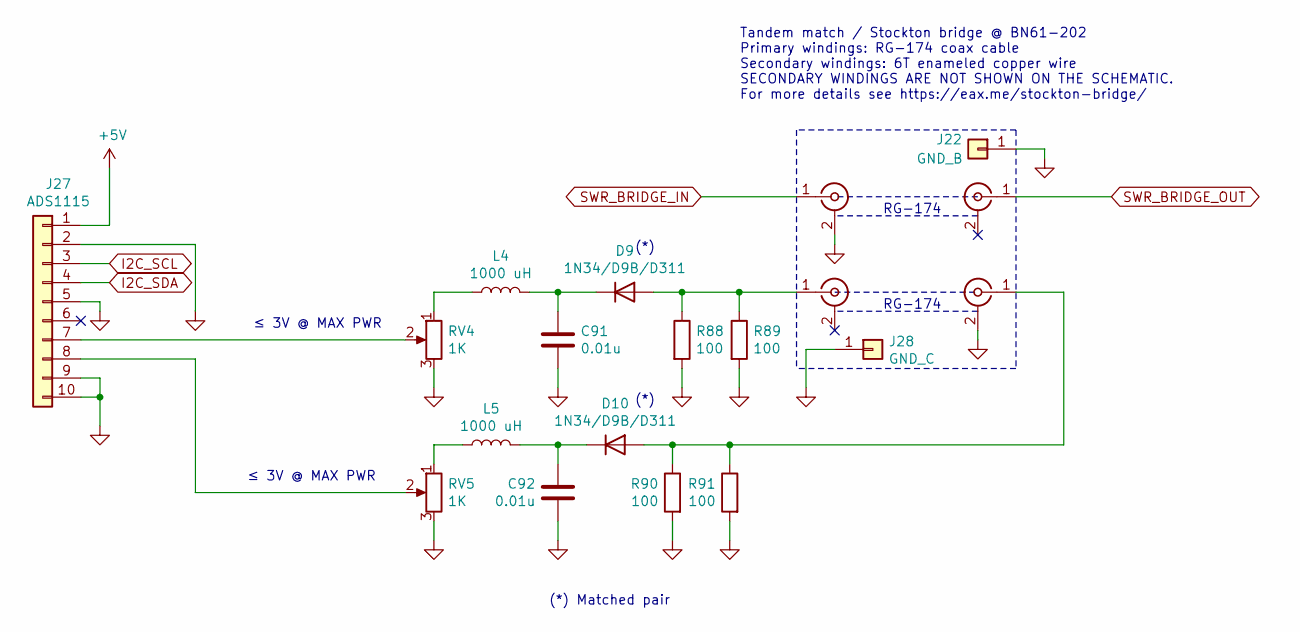
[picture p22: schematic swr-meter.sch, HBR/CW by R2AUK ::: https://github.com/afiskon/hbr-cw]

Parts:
C91, C92: 0.01u; C_0805_2012Metric_Pad1.15x1.40mm_HandSolder
D9, D10: 1N34/D9B/D311; D_DO-41_SOD81_P10.16mm_Horizontal
J22: GND_B; PinHeader_1x01_P2.54mm_Vertical
J23: STK_A; PinHeader_1x02_P2.54mm_Vertical
J24: STK_B; PinHeader_1x02_P2.54mm_Vertical
J25: STK_C; PinHeader_1x02_P2.54mm_Vertical
J26: STK_D; PinHeader_1x02_P2.54mm_Vertical
J27: ADS1115; PinSocket_1x10_P2.54mm_Vertical
J28: GND_C; PinHeader_1x01_P2.54mm_Vertical
L4, L5: 1000 uH; L_Axial_L6.6mm_D2.7mm_P10.16mm_Horizontal_Vishay_IM-2
R88, R89, R90, R91: 100; R_0805_2012Metric_Pad1.15x1.40mm_HandSolder
RV4, RV5: 1K; Potentiometer_Bourns_3296W_Vertical

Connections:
+5V: J27.1; also elsewhere on the board
GND: C91.2, C92.2, J22.1, J23.2 (Ext), J26.2 (Ext), J27.2, J27.5, J27.9, J27.10, J28.1, R88.2, R89.2, R90.2, R91.2, RV4.3, RV5.3; also elsewhere on the board
I2C_SCL: J27.3; also elsewhere on the board
I2C_SDA: J27.4; also elsewhere on the board
unnamed: C91.1, D9.1 (K), L4.2
unnamed: C92.1, D10.1 (K), L5.1
unnamed: D9.2 (A), J25.1 (In), R88.1, R89.1
unnamed: D10.2 (A), J26.1 (In), R90.1, R91.1
unnamed: J27.7, RV4.2
unnamed: J27.8, RV5.2
unnamed: L4.1, RV4.1
unnamed: L5.2, RV5.1
SWR_BRIDGE_IN: J23.1 (In); also elsewhere on the board
SWR_BRIDGE_OUT: J24.1 (In); also elsewhere on the board

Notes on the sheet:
Tandem match / Stockton bridge @ BN61-202 Primary windings: RG-174 coax cable Secondary windings: 6T enameled copper wire SECONDARY WINDINGS ARE NOT SHOWN ON THE SCHEMATIC. For more details see https://eax.me/stockton-bridge/
RG-174
≤ 3V @ MAX PWR
(*)
(*) Matched pair

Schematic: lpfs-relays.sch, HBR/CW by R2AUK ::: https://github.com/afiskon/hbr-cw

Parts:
C89, C90: 1000p; C_0805_2012Metric_Pad1.15x1.40mm_HandSolder
C93, C94, C95, C96, C97, C98, C99, C100, C101, C102, C103, C104, C105, C106, C107, C108, C109, C110, C113, C114: 0.1u; C_0805_2012Metric_Pad1.15x1.40mm_HandSolder
D11, D12, D13, D14, D15, D16, D17, D18, D19, D20: M7; D_SMA_Handsoldering
K3, K4, K5, K6, K7, K8, K9, K10, K11, K12: HFD4/12S; Relay_DPDT_Omron_G6K-2F-Y
L6: 3.6u; L_Radial_L12.6mm_W12.6mm_Px9.52mm_Py9.52mm_Pulse_LP-37
Q20, Q21, Q22, Q23, Q24: MMBT3904; SOT-23
R92, R93, R94, R95, R96: 470; R_0805_2012Metric_Pad1.15x1.40mm_HandSolder

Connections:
GND: C93.2, C94.2, C95.2, C96.2, C97.2, C98.2, C99.2, C100.2, C101.2, C102.2, C103.2, C104.2, C105.2, C106.2, C107.2, C108.2, C109.2, C110.2, C113.2, C114.2, K3.5, K3.6, K3.7, K4.5, K4.6, K4.7, K5.5, K5.6, K5.7, K6.5, K6.6, K6.7, K7.5, K7.6, K7.7, K8.5, K8.6, K8.7, K9.5, K9.6, K9.7, K10.5, K10.6, K10.7, K11.5, K11.6, K11.7, K12.5, K12.6, K12.7, L6.2, Q20.2 (E), Q21.2 (E), Q22.2 (E), Q23.2 (E), Q24.2 (E); also elsewhere on the board
HPF_IN: C89.2; also elsewhere on the board
LPF10_CTL: C109.1, R96.2; also elsewhere on the board
LPF10_GND: D17.2 (A), D18.2 (A), K9.8, K10.8, Q24.3 (C)
LPF10_IN: K9.4; also elsewhere on the board
LPF10_OUT: K10.4; also elsewhere on the board
LPF15_CTL: C107.1, R95.2; also elsewhere on the board
LPF15_GND: D13.2 (A), D14.2 (A), K5.8, K6.8, Q23.3 (C)
LPF15_IN: K5.4; also elsewhere on the board
LPF15_OUT: K6.4; also elsewhere on the board
LPF20_CTL: C101.1, R94.2; also elsewhere on the board
LPF20_GND: D19.2 (A), D20.2 (A), K11.8, K12.8, Q22.3 (C)
LPF20_IN: K11.4; also elsewhere on the board
LPF20_OUT: K12.4; also elsewhere on the board
LPF40_CTL: C99.1, R93.2; also elsewhere on the board
LPF40_GND: D15.2 (A), D16.2 (A), K7.8, K8.8, Q21.3 (C)
LPF40_IN: K7.4; also elsewhere on the board
LPF40_OUT: K8.4; also elsewhere on the board
LPF80_CTL: C97.1, R92.2; also elsewhere on the board
LPF80_GND: D11.2 (A), D12.2 (A), K3.8, K4.8, Q20.3 (C)
LPF80_IN: K3.4; also elsewhere on the board
LPF80_OUT: K4.4; also elsewhere on the board
LPFS_IN: C90.1, K3.3, K5.3, K7.3, K9.3, K11.3
unnamed: C89.1, C90.2, L6.1
unnamed: C98.1, Q20.1 (B), R92.1
unnamed: C100.1, Q21.1 (B), R93.1
unnamed: C102.1, Q22.1 (B), R94.1
unnamed: C108.1, Q23.1 (B), R95.1
unnamed: C110.1, Q24.1 (B), R96.1
SWR_BRIDGE_IN: K4.3, K6.3, K8.3, K10.3, K12.3; also elsewhere on the board
VCC: C93.1, C94.1, C95.1, C96.1, C103.1, C104.1, C105.1, C106.1, C113.1, C114.1, D11.1 (K), D12.1 (K), D13.1 (K), D14.1 (K), D15.1 (K), D16.1 (K), D17.1 (K), D18.1 (K), D19.1 (K), D20.1 (K), K3.1, K4.1, K5.1, K6.1, K7.1, K8.1, K9.1, K10.1, K11.1, K12.1; also elsewhere on the board

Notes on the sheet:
1 MHz HPF (optional) 3.6u = 20T @ 2 x T50-6 = 25T @ T68-2

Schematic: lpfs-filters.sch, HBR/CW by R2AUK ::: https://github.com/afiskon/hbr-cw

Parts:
C116, C117, C127, C128, C177, C187: 470p; C_0805_2012Metric_Pad1.15x1.40mm_HandSolder
C119, C120, C124, C125, C179, C181, C185: 820p; C_0805_2012Metric_Pad1.15x1.40mm_HandSolder
C121, C123: 680p; C_0805_2012Metric_Pad1.15x1.40mm_HandSolder
C122: 390p; C_0805_2012Metric_Pad1.15x1.40mm_HandSolder
C131, C143, C165, C170: 150p; C_0805_2012Metric_Pad1.15x1.40mm_HandSolder
C132, C135, C139, C142, C150, C154: 10p; C_0805_2012Metric_Pad1.15x1.40mm_HandSolder
C134, C136, C140, C164, C169: 270p; C_0805_2012Metric_Pad1.15x1.40mm_HandSolder
C137, C180, C184: 22p; C_0805_2012Metric_Pad1.15x1.40mm_HandSolder
C146, C148, C149, C155, C156, C158: 100p; C_0805_2012Metric_Pad1.15x1.40mm_HandSolder
C147, C157, C162, C172: 18p; C_0805_2012Metric_Pad1.15x1.40mm_HandSolder
C152, C161, C166, C168, C173: 220p; C_0805_2012Metric_Pad1.15x1.40mm_HandSolder
C182: 56p; C_0805_2012Metric_Pad1.15x1.40mm_HandSolder
L7, L10: 2.9u; L_Radial_L12.6mm_W12.6mm_Px9.52mm_Py9.52mm_Pulse_LP-37
L8, L9: 3.2u; L_Radial_L12.6mm_W12.6mm_Px9.52mm_Py9.52mm_Pulse_LP-37
L11, L14: 0.5u; L_Toroid_Vertical_L13.0mm_W6.5mm_P5.60mm
L12, L13: 0.6u; L_Toroid_Vertical_L13.0mm_W6.5mm_P5.60mm
L15, L18: 0.35u; L_Toroid_Vertical_L13.0mm_W6.5mm_P5.60mm
L16, L17: 0.4u; L_Toroid_Vertical_L13.0mm_W6.5mm_P5.60mm
L19, L22: 0.7u; L_Toroid_Vertical_L13.0mm_W6.5mm_P5.60mm
L20, L21: 0.8u; L_Toroid_Vertical_L13.0mm_W6.5mm_P5.60mm
L23, L26: 1.4u; L_Toroid_Vertical_L13.0mm_W6.5mm_P5.60mm
L24, L25: 1.6u; L_Toroid_Vertical_L13.0mm_W6.5mm_P5.60mm

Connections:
GND: C116.2, C117.2, C119.2, C120.2, C121.2, C122.2, C123.2, C124.2, C125.2, C127.2, C128.2, C131.2, C132.2, C134.2, C135.2, C136.2, C137.2, C139.2, C140.2, C142.2, C143.2, C146.2, C147.2, C148.2, C149.2, C150.2, C152.2, C154.2, C155.2, C156.2, C157.2, C158.2, C161.2, C162.2, C164.2, C165.2, C166.2, C168.2, C169.2, C170.2, C172.2, C173.2, C177.2, C179.2, C180.2, C181.2, C182.2, C184.2, C185.2, C187.2; also elsewhere on the board
LPF10_IN: C146.1, C147.1, L15.1; also elsewhere on the board
LPF10_OUT: C157.1, C158.1, L18.1; also elsewhere on the board
LPF15_IN: C131.1, C132.1, L11.1; also elsewhere on the board
LPF15_OUT: C142.1, C143.1, L14.1; also elsewhere on the board
LPF20_IN: C161.1, C162.1, L19.1; also elsewhere on the board
LPF20_OUT: C172.1, C173.1, L22.1; also elsewhere on the board
LPF40_IN: C177.1, L23.1; also elsewhere on the board
LPF40_OUT: C187.1, L26.1; also elsewhere on the board
LPF80_IN: C116.1, C117.1, L7.1; also elsewhere on the board
LPF80_OUT: C127.1, C128.1, L10.1; also elsewhere on the board
unnamed: C119.1, C120.1, L7.2, L8.1
unnamed: C121.1, C122.1, C123.1, L8.2, L9.2
unnamed: C124.1, C125.1, L9.1, L10.2
unnamed: C134.1, C135.1, L11.2, L12.1
unnamed: C136.1, C137.1, L12.2, L13.2
unnamed: C139.1, C140.1, L13.1, L14.2
unnamed: C148.1, C149.1, C150.1, L15.2, L16.1
unnamed: C152.1, L16.2, L17.2
unnamed: C154.1, C155.1, C156.1, L17.1, L18.2
unnamed: C164.1, C165.1, L19.2, L20.1
unnamed: C166.1, C168.1, L20.2, L21.2
unnamed: C169.1, C170.1, L21.1, L22.2
unnamed: C179.1, C180.1, L23.2, L24.1
unnamed: C181.1, C182.1, L24.2, L25.2
unnamed: C184.1, C185.1, L25.1, L26.2

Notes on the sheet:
2.9u = 18T @ 2x T50-6 = 21T @ T68-2
3.2u = 19T @ 2x T50-6 = 23T @ T68-2
0.5u = 10T @ T50-6
0.6u = 11T @ T50-6
0.35u = 8T @ T50-6
0.40u = 9T @ T50-6
0.7u = 12T @ T50-6
0.8u = 13T @ T50-6
1.4u = 18T @ T50-6
1.6u = 19T @ T50-6

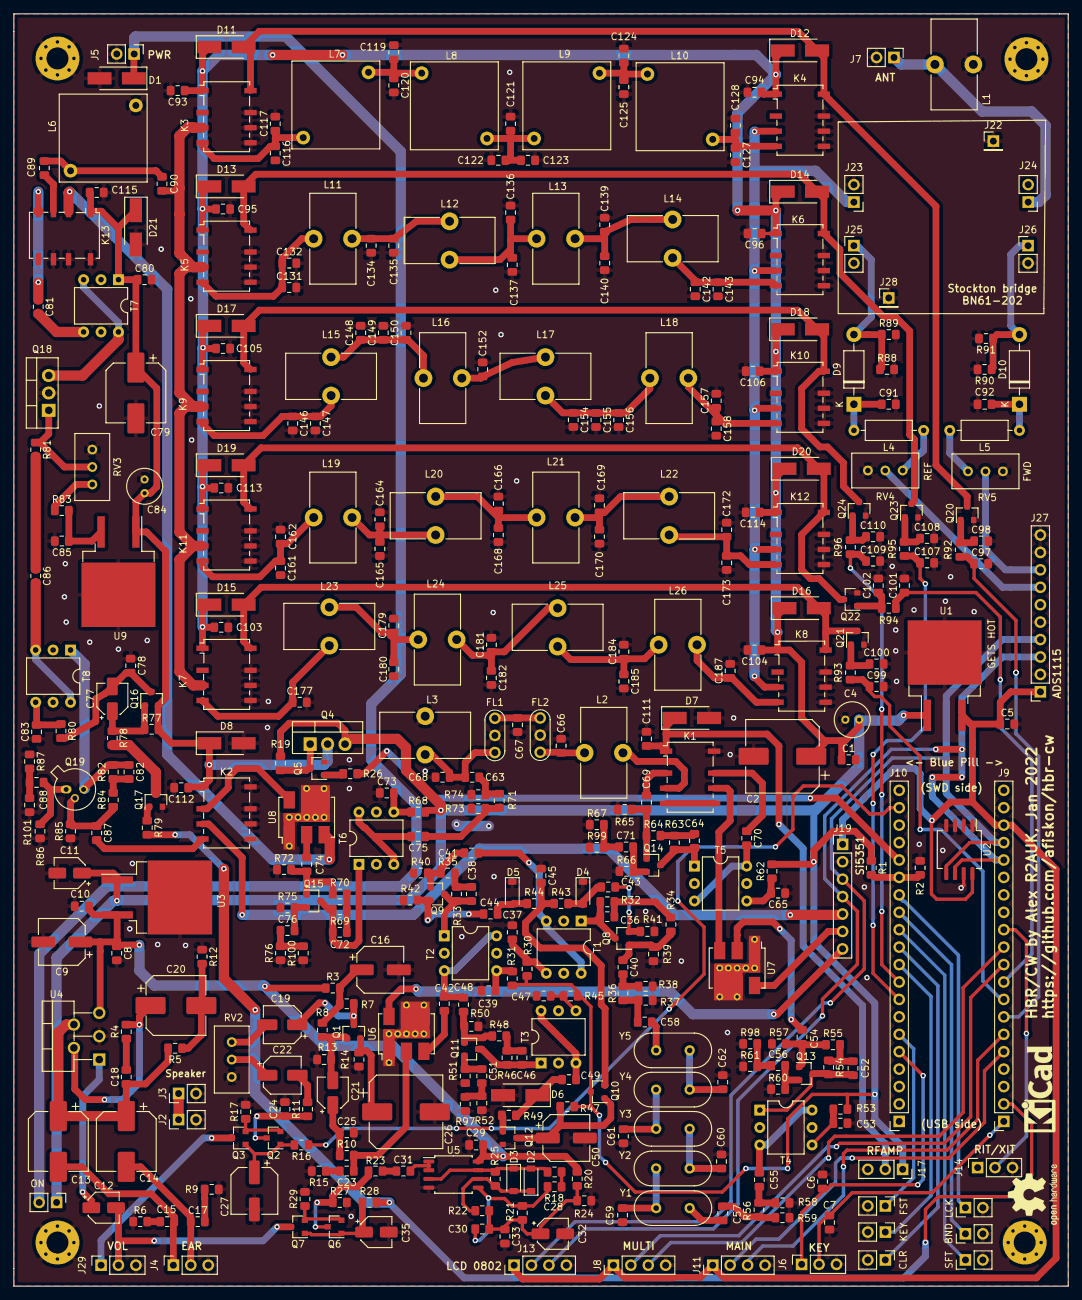
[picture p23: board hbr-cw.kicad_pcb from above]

Board: 2 copper layers, 153.7 x 185.4 mm, 411 parts (0 on the bottom side), 209 nets.

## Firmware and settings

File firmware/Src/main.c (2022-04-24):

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

/* Includes ------------------------------------------------------------------*/
#include "main.h"

/* USER CODE BEGIN Includes */
#include <string.h>
#include <stdlib.h>
#include <stdbool.h>
#include "si5351.h"
#include "lcd.h"
#include "spur_masking.h"

/* USER CODE END Includes */

ADC_HandleTypeDef hadc1;

I2C_HandleTypeDef hi2c1;

TIM_HandleTypeDef htim1;
TIM_HandleTypeDef htim2;

/* USER CODE BEGIN PV */

/* USER CODE END PV */

void SystemClock_Config(void);
static void MX_GPIO_Init(void);
static void MX_TIM1_Init(void);
static void MX_I2C1_Init(void);
static void MX_ADC1_Init(void);
static void MX_TIM2_Init(void);
/* USER CODE BEGIN PFP */

/* USER CODE END PFP */

/* USER CODE BEGIN 0 */

#define CH_BFO1 0
#define CH_BFO2 1
#define CH_VFO_AND_CW  2

// IF2 Frequency can be tweaked a bit to reach lower insertion
// losses of the filter and/or to supress spurious signals

const int32_t IF2Frequency = 45000000 - 10000 /* supress spurs */;
const int32_t AlternativeIF2Frequency = 45000000 - 11500;

const int32_t XtalFilterCenterFrequency = 8998250;
const int32_t si5351_correction = 6468;

/* Adjust for used rotary encoders */
#define MAIN_DELTA_DIV 20
#define MAIN_DELTA_MULT -1
#define MULTI_DELTA_DIV 1
#define MULTI_DELTA_MULT 1

int32_t Fvfo = 1000000; // dummy value, will be changed below

const uint8_t ads1115_i2c_addr = (0x48 << 1);
typedef enum {
	ADS1115_CHANNEL_0 = 0,
	ADS1115_CHANNEL_1 = 1,
	ADS1115_CHANNEL_2 = 2,
	ADS1115_CHANNEL_3 = 3,
} ADS1115Channel_t;

const uint8_t eeprom_i2c_addr = (0x50 << 1);
#define KEYER_CONFIG_EEPROM_ADDR        0x0000

typedef enum {
	CLAR_MODE_DISABLED = 0,
	CLAR_MODE_RIT = 1,
	CLAR_MODE_XIT = 2,
} ClarMode_t;

bool lockMode = false;
bool fastMode = false;
bool bandMode = false;
bool shiftMode = false;
ClarMode_t clarMode = CLAR_MODE_DISABLED;

int32_t clarOffset = 0;
int32_t shiftOffset = 0;

int32_t sendStart = 0;
int32_t sendFinish = 0;
int32_t keyReadTimeout = 0;
int32_t sendTimeout = 0;
bool isSending = false;

typedef enum {
	CW_SEND_NONE = 0,
	CW_SEND_DIT = 1,
	CW_SEND_DAH = 2,
} CwSend_t;

CwSend_t lastSent = CW_SEND_NONE;
CwSend_t nextSend = CW_SEND_NONE;

typedef struct {
    uint16_t checksum;
    bool straightKey;
    int32_t speedWPM;
    int32_t ditTimeMs;
} KeyerConfig_t;

KeyerConfig_t keyerConfig = {
	.checksum = 0,
	.straightKey = false,
	.speedWPM = 18,

	// ditTimeMs = 60*1000/(50*WPM)
	// where 50 is the length in dits of "PARIS "
	// see https://morsecode.world/international/timing.html
	.ditTimeMs = 67,
};

bool inTransmitMode = false;
bool inCWTrainerMode = false;

#define BUTTON_DEBOUNCE_TIME_MS 200
typedef enum {
	BUTTON_STATUS_PRESSED = 0,
	BUTTON_STATUS_RELEASED = 1,
	BUTTON_STATUS_DEBOUNCE = 2,
} ButtonStatus_t;

typedef enum {
	USE_LPF_80 = 0,
	USE_LPF_40 = 1,
	USE_LPF_20 = 2,
	USE_LPF_15 = 3,
	USE_LPF_10 = 4,
} UseLPF_t;

typedef struct {
    int32_t minFreq;
    int32_t maxFreq;
    int32_t lastFreq;
    UseLPF_t lpf;
    /*
     * Compensate for losses in RG-174, frequency response of the given
     * PA depending on the used transistor, imperfections of the LPFs, etc.
     */
    si5351DriveStrength_t txDriveStrength;
} BandInfo_t;

int32_t currentBand = 3; // default: 20m

#define BANDS_NUMBER 8
BandInfo_t bands[BANDS_NUMBER] = {
	{
		.minFreq  = 3500000,
		.maxFreq  = 3570000,
		.lastFreq = 3560000,
		.lpf = USE_LPF_80,
		.txDriveStrength = SI5351_DRIVE_STRENGTH_2MA,
	},
	{
		.minFreq  = 7000000,
		.maxFreq  = 7040000,
		.lastFreq = 7030000,
		.lpf = USE_LPF_40,
		.txDriveStrength = SI5351_DRIVE_STRENGTH_2MA,
	},
	{
		.minFreq  = 10100000,
		.maxFreq  = 10130000,
		.lastFreq = 10116000,
		.lpf = USE_LPF_20,
		.txDriveStrength = SI5351_DRIVE_STRENGTH_2MA,
	},
	{
		.minFreq  = 14000000,
		.maxFreq  = 14070000,
		.lastFreq = 14060000,
		.lpf = USE_LPF_20,
		.txDriveStrength = SI5351_DRIVE_STRENGTH_2MA,
	},
	{
		.minFreq  = 18068000,
		.maxFreq  = 18095000,
		.lastFreq = 18086000,
		.lpf = USE_LPF_15,
		.txDriveStrength = SI5351_DRIVE_STRENGTH_2MA,
	},
	{
		.minFreq  = 21000000,
		.maxFreq  = 21070000,
		.lastFreq = 21060000,
		.lpf = USE_LPF_15,
		.txDriveStrength = SI5351_DRIVE_STRENGTH_8MA,
	},
	{
		.minFreq  = 24890000,
		.maxFreq  = 24915000,
		.lastFreq = 24906000,
		.lpf = USE_LPF_10,
		.txDriveStrength = SI5351_DRIVE_STRENGTH_8MA,
	},
	{
		.minFreq  = 28000000,
		.maxFreq  = 28070000,
		.lastFreq = 28060000,
		.lpf = USE_LPF_10,
		.txDriveStrength = SI5351_DRIVE_STRENGTH_8MA,
	},
};



// http://en.wikipedia.org/wiki/Jenkins_hash_function
uint32_t jenkinsHash(const uint8_t *data, const size_t len) {
  uint32_t hash, i;
  for(hash = i = 0; i < len; ++i) {
    hash += data[i];
    hash += (hash << 10);
    hash ^= (hash >> 6);
  }
  hash += (hash << 3);
  hash ^= (hash >> 11);
  hash += (hash << 15);
  return hash;
}

void loadKeyerConfig() {
    HAL_StatusTypeDef status;
    uint16_t savedChecksum;
    KeyerConfig_t savedKeyerConfig;

    for(;;) {
        status = HAL_I2C_IsDeviceReady(&hi2c1, eeprom_i2c_addr, 3, HAL_MAX_DELAY);
        if(status == HAL_OK)
            break;
    }

    HAL_I2C_Mem_Read(&hi2c1, eeprom_i2c_addr, KEYER_CONFIG_EEPROM_ADDR, I2C_MEMADD_SIZE_16BIT,
        (uint8_t*)&savedKeyerConfig, sizeof(savedKeyerConfig), HAL_MAX_DELAY);

    savedChecksum = savedKeyerConfig.checksum;
    savedKeyerConfig.checksum = 0;

    if((jenkinsHash((const uint8_t*)&savedKeyerConfig, sizeof(savedKeyerConfig)) & 0xFFFF) == savedChecksum) {
        keyerConfig = savedKeyerConfig;
    } else {
        LCD_Goto(0, 0);
        LCD_SendString("CHECKSUM");
        LCD_Goto(1, 0);
        LCD_SendString(" ERROR! ");
        HAL_Delay(2000);
        LCD_Clear();
    }
}

void saveKeyerConfig() {
    HAL_StatusTypeDef status;
    uint16_t checksum;
    keyerConfig.checksum = 0;

    checksum = (jenkinsHash((const uint8_t*)&keyerConfig, sizeof(keyerConfig)) & 0xFFFF);
    keyerConfig.checksum = checksum;

    for(;;) {
        status = HAL_I2C_IsDeviceReady(&hi2c1, eeprom_i2c_addr, 3, HAL_MAX_DELAY);
        if(status == HAL_OK)
            break;
    }

    HAL_I2C_Mem_Write(&hi2c1, eeprom_i2c_addr, KEYER_CONFIG_EEPROM_ADDR, I2C_MEMADD_SIZE_16BIT,
        (uint8_t*)&keyerConfig, sizeof(keyerConfig), HAL_MAX_DELAY);
}

double getADS1115Voltage(ADS1115Channel_t ch) {
	int16_t reading;
	uint8_t conversion[2];
	uint8_t config[] = { 0xC1, 0x83 };

	switch(ch) {
	case ADS1115_CHANNEL_0:
		config[0] = 0xC1;
		break;
	case ADS1115_CHANNEL_1:
		config[0] = 0xD1;
		break;
	case ADS1115_CHANNEL_2:
		config[0] = 0xE1;
		break;
	case ADS1115_CHANNEL_3:
		config[0] = 0xF1;
		break;
	}

    // Write to the config register (0x01):
    // byte 1: single conversion, channel number, FSR +/- 6.114 V, single shot
    // byte 2: 128 SPS, default comparator options, ALTR pin High-Z
    // For more detauls see section "9.6 Register Map" of the datasheet.
	HAL_I2C_Mem_Write(&hi2c1, ads1115_i2c_addr, 0x01, I2C_MEMADD_SIZE_8BIT,
		config, sizeof(config), HAL_MAX_DELAY);

	// Read from the conversion register (0x00)
	HAL_I2C_Mem_Read(&hi2c1, ads1115_i2c_addr, 0x00, I2C_MEMADD_SIZE_8BIT,
		conversion, sizeof(conversion), HAL_MAX_DELAY);

	reading = ((int16_t)conversion[0] << 8) | (int16_t)conversion[1];
	return ((double)reading) * (6.114 / 32768.0);
}

void changeKeyerSpeed(int32_t delta) {
	keyerConfig.speedWPM += delta;
	if(keyerConfig.speedWPM < 10) {
		keyerConfig.speedWPM = 9;
		keyerConfig.straightKey = true;
		keyerConfig.ditTimeMs = 60*1000/(50*15); // as for 15 WPM
	} else {
		keyerConfig.straightKey = false;
		if(keyerConfig.speedWPM > 30) {
			keyerConfig.speedWPM = 30;
		}

		keyerConfig.ditTimeMs = 60*1000/(50*keyerConfig.speedWPM);
	}
}

void SetupCLK(uint8_t output, int32_t Fclk, si5351DriveStrength_t driveStrength) {
	static bool pllSetupDone = false;
	si5351PLLConfig_t pll_conf;
	si5351OutputConfig_t out_conf;

	si5351_Calc(Fclk, &pll_conf, &out_conf);
	if(!pllSetupDone) {
		si5351_SetupPLL(SI5351_PLL_A, &pll_conf);
		pllSetupDone = true;
	}
	si5351_SetupOutput(output, SI5351_PLL_A, driveStrength, &out_conf);
}

// Switch on/off ENABLE_RX output
void enableRx(bool enable) {
	HAL_GPIO_WritePin(GPIOC, GPIO_PIN_13, enable ? GPIO_PIN_SET : GPIO_PIN_RESET);
}

// Switch on/off ENABLE_TX output
void enableTx(bool enable) {
	HAL_GPIO_WritePin(GPIOA, GPIO_PIN_0, enable ? GPIO_PIN_SET : GPIO_PIN_RESET);
}

void changeFrequency(int32_t delta, bool force) {
	static int32_t prevFvfo = 0;
	static int32_t prevFbfo1 = 0;
	static int32_t prevFbfo2 = 0;
	if((!force) && lockMode) {
		return;
	}

	if(fastMode) {
		delta *= 10;
	}
	bands[currentBand].lastFreq += 100*delta;
	if(fastMode && (delta != 0)) {
		bands[currentBand].lastFreq -= bands[currentBand].lastFreq % 1000;
	}

	if(bands[currentBand].lastFreq < bands[currentBand].minFreq) {
		bands[currentBand].lastFreq = bands[currentBand].minFreq;
	} else if(bands[currentBand].lastFreq > bands[currentBand].maxFreq) {
		bands[currentBand].lastFreq = bands[currentBand].maxFreq;
	}

	Fvfo = bands[currentBand].lastFreq;
	if(clarMode == CLAR_MODE_RIT) {
		Fvfo += clarOffset;
	}

	int32_t Fbfo1 = XtalFilterCenterFrequency + 1000;
	int32_t Fbfo2 = IF2Frequency + XtalFilterCenterFrequency;

	// mask the spurs
	const SpurMaskInfo* maskInfo = getSpurMaskingInfo(Fvfo);
	if(maskInfo != NULL) {
		Fvfo += maskInfo->clar;
		Fbfo1 -= maskInfo->shift;
		Fbfo2 -= maskInfo->shift;
		if(maskInfo->useAlternativeIF2Frequency) {
			Fbfo2 += AlternativeIF2Frequency - IF2Frequency;
			Fvfo += AlternativeIF2Frequency - IF2Frequency;
		}
	}

	Fvfo += IF2Frequency;

	if(shiftMode) {
		// SHIFT basically moves XtalFilterCenterFrequency
		Fbfo1 -= shiftOffset;
		Fbfo2 -= shiftOffset;
	}

	if(force || (Fbfo1 != prevFbfo1)) {
		SetupCLK(CH_BFO1, Fbfo1, SI5351_DRIVE_STRENGTH_4MA);
	}

	if(force || (Fbfo2 != prevFbfo2)) {
		SetupCLK(CH_BFO2, Fbfo2, SI5351_DRIVE_STRENGTH_4MA);	
	}

	if(force || (Fvfo != prevFvfo)) {
		SetupCLK(CH_VFO_AND_CW, Fvfo, SI5351_DRIVE_STRENGTH_4MA);	
	}

	prevFvfo = Fvfo;
	prevFbfo1 = Fbfo1;
	prevFbfo2 = Fbfo2;
}

void displayKeyerSettings() {
	char buff[16];
	if(keyerConfig.straightKey) {
		LCD_Goto(0, 0);
		LCD_SendString("SPEED --");
		LCD_Goto(1, 0);
		LCD_SendString("STRAIGHT");
	} else {
		snprintf(buff, sizeof(buff), "SPEED %02ld", keyerConfig.speedWPM);
		LCD_Goto(0, 0);
		LCD_SendString(buff);
		LCD_Goto(1, 0);
		LCD_SendString("IAMBIC  ");
	}
}

void displayFrequency() {
	char buff[16];
	snprintf(buff, sizeof(buff), "%02ld.%03ld.%01ld", 
		bands[currentBand].lastFreq / 1000000,
		(bands[currentBand].lastFreq % 1000000) / 1000,
		(bands[currentBand].lastFreq % 1000) / 100);

    LCD_Goto(0, 0);
    LCD_SendString(buff);
}

void displayVoltageOrMode(bool force) {
	// don't forget to add '-u _printf_float' to LDFLAGS
	char buff[16];
	static int32_t lastVoltageUpdate = 0;
	static int32_t lastVoltageValue = 0;
    static double prevVoltage = 0.0;
	
	if(force) {
		LCD_Goto(1, 0);
		if(fastMode) {
			snprintf(buff, sizeof(buff), "%s FAST",
				shiftMode ? "SFT" :
					(clarMode == CLAR_MODE_DISABLED ? "RX " :
						(clarMode == CLAR_MODE_RIT ? "RIT" : "XIT")));
			LCD_SendString(buff);
			return;
		} else if(lockMode) {
			snprintf(buff, sizeof(buff), "%s LOCK",
				shiftMode ? "SFT" :
					(clarMode == CLAR_MODE_DISABLED ? "RX " :
						(clarMode == CLAR_MODE_RIT ? "RIT" : "XIT")));
			LCD_SendString(buff);
			return;
		} else if(bandMode) {
			snprintf(buff, sizeof(buff), "%s BAND",
				shiftMode ? "SFT" :
					(clarMode == CLAR_MODE_DISABLED ? "RX " :
						(clarMode == CLAR_MODE_RIT ? "RIT" : "XIT")));
			LCD_SendString(buff);
			return;
		} else if(shiftMode) {
			snprintf(buff, sizeof(buff), "SFT%s%04d",
				shiftOffset < 0 ? "-" : "+",
				abs(shiftOffset));
			LCD_SendString(buff);
			return;
		} else if(clarMode != CLAR_MODE_DISABLED) {
			snprintf(buff, sizeof(buff), "%s%s%04d",
				clarMode == CLAR_MODE_RIT ? "RIT" : "XIT",
				clarOffset < 0 ? "-" : "+",
				abs(clarOffset));
			LCD_SendString(buff);
			return;
		}
	}

	uint32_t now = HAL_GetTick();
	if(now - lastVoltageUpdate > 1000) {
	    HAL_ADC_PollForConversion(&hadc1, HAL_MAX_DELAY);
		lastVoltageValue = HAL_ADC_GetValue(&hadc1);
		lastVoltageUpdate = now;
	}

	double voltage = ((double)(lastVoltageValue)-1220.0)/190.0 + 6.9;
    if((!force) && (abs((int)(voltage*10) - (int)(prevVoltage*10)) <= 1)) {
		return;
	}

	prevVoltage = voltage;
	if(voltage < 9.95) {
		snprintf(buff, sizeof(buff), "RX  %.1fV", voltage);
	} else {
		snprintf(buff, sizeof(buff), "RX %.1fV", voltage);
	}

	LCD_Goto(1, 0);
	LCD_SendString(buff);
}

/*
 * Don't check SWR when the carrier is not transmitted.
 * This reduces digital noise in the headphones.
 */ 
bool checkSWR = false;

void keyDown() {
	// CW tone ON
	HAL_GPIO_WritePin(GPIOB, GPIO_PIN_13, GPIO_PIN_SET);
	if(inTransmitMode) {
		si5351_EnableOutputs(1 << CH_VFO_AND_CW);
		checkSWR = true;
	}
}

void keyUp() {
	// CW tone OFF
	HAL_GPIO_WritePin(GPIOB, GPIO_PIN_13, GPIO_PIN_RESET);
	if(inTransmitMode) {
		si5351_EnableOutputs(0);
		checkSWR = false;
	}
}

void switchLPFs(UseLPF_t lpf) {
	HAL_GPIO_WritePin(GPIOA, GPIO_PIN_10, lpf == USE_LPF_80 ? GPIO_PIN_SET : GPIO_PIN_RESET);
	HAL_GPIO_WritePin(GPIOA, GPIO_PIN_11, lpf == USE_LPF_40 ? GPIO_PIN_SET : GPIO_PIN_RESET);
	HAL_GPIO_WritePin(GPIOA, GPIO_PIN_12, lpf == USE_LPF_20 ? GPIO_PIN_SET : GPIO_PIN_RESET);
	HAL_GPIO_WritePin(GPIOB, GPIO_PIN_0,  lpf == USE_LPF_15 ? GPIO_PIN_SET : GPIO_PIN_RESET);
	HAL_GPIO_WritePin(GPIOA, GPIO_PIN_7,  lpf == USE_LPF_10 ? GPIO_PIN_SET : GPIO_PIN_RESET);
}

void changeBand(int32_t delta) {
	currentBand += delta;
	while(currentBand < 0) {
		currentBand += BANDS_NUMBER;
	}
	currentBand %= BANDS_NUMBER;

	switchLPFs(bands[currentBand].lpf);
	changeFrequency(0, false);
	si5351_EnableOutputs((1 << CH_VFO_AND_CW)|(1 << CH_BFO1)|(1 << CH_BFO2));
	displayFrequency();
}

void enterCWTrainerMode() {
	if(inCWTrainerMode) {
		return;
	}

	enableRx(false);
	inCWTrainerMode = true;
}

void leaveCWTrainerMode() {
	if(!inCWTrainerMode) {
		return;
	}

	enableRx(true);
	inCWTrainerMode = false;
}

void ensureTransmitMode() {
	if(inTransmitMode) {
		return;
	}

	int32_t targetFrequency = bands[currentBand].lastFreq;
	if(clarMode == CLAR_MODE_XIT) {
		targetFrequency += clarOffset;
	}

	si5351_EnableOutputs(0);
	SetupCLK(CH_VFO_AND_CW, targetFrequency, bands[currentBand].txDriveStrength);
	enableRx(false);
	enableTx(true);

	LCD_Goto(1, 0);
	LCD_SendString("TRANSMIT");

	inTransmitMode = true;
}

void ensureReceiveMode() {
	if(!inTransmitMode) {
		return;
	}
	enableTx(false);
	enableRx(true);

	// Restore the original VFO.
	// Using force=true because the VFO has changed, but changeFrequency()
	// doesn't know about it.
	changeFrequency(0, true);
	si5351_EnableOutputs((1 << CH_VFO_AND_CW)|(1 << CH_BFO1)|(1 << CH_BFO2));
	displayVoltageOrMode(true);
	inTransmitMode = false;
}

ButtonStatus_t buttonPressed(GPIO_TypeDef *GPIOx, uint16_t GPIO_Pin, uint32_t* lastPressed) {
	if(HAL_GPIO_ReadPin(GPIOx, GPIO_Pin) == GPIO_PIN_RESET) {
		uint32_t now = HAL_GetTick();
		if(now - *lastPressed > BUTTON_DEBOUNCE_TIME_MS) {
			*lastPressed = now;
			return BUTTON_STATUS_PRESSED;
		} else {
			return BUTTON_STATUS_DEBOUNCE;
		}
	}
	return BUTTON_STATUS_RELEASED;
}

bool buttonDitPressed() {
	return (HAL_GPIO_ReadPin(GPIOB, GPIO_PIN_11) == GPIO_PIN_RESET);
}

bool buttonDahPressed() {
	return (HAL_GPIO_ReadPin(GPIOB, GPIO_PIN_12) == GPIO_PIN_RESET);
}

bool switchRitMode() {
	return (HAL_GPIO_ReadPin(GPIOB, GPIO_PIN_4) == GPIO_PIN_RESET);
}

ButtonStatus_t buttonBandPressed() {
	static uint32_t lastPressed = 0;
	return buttonPressed(GPIOA, GPIO_PIN_3, &lastPressed);
}

ButtonStatus_t buttonFastPressed() {
	static uint32_t lastPressed = 0;
	return buttonPressed(GPIOB, GPIO_PIN_10, &lastPressed);
}

ButtonStatus_t buttonLockPressed() {
	static uint32_t lastPressed = 0;
	return buttonPressed(GPIOA, GPIO_PIN_2, &lastPressed);
}

ButtonStatus_t buttonClarPressed() {
	static uint32_t lastPressed = 0;
	return buttonPressed(GPIOA, GPIO_PIN_5, &lastPressed);
}

ButtonStatus_t buttonShiftPressed() {
	static uint32_t lastPressed = 0;
	return buttonPressed(GPIOA, GPIO_PIN_4, &lastPressed);
}

ButtonStatus_t buttonKeyerPressed() {
	static uint32_t lastPressed = 0;
	return buttonPressed(GPIOA, GPIO_PIN_6, &lastPressed);
}

// `straightKeyerKeyIsDown` is used to avoid calling keyUp()/keyDown() if we did it already.
// Calling HAL_GPIO_WritePin() too often generates a hearable noise.
bool straightKeyerKeyIsDown;

void initStraightKeyer() {
	straightKeyerKeyIsDown = false;
}

void processStraightKeyerLogic(bool pressed) {
	if(pressed) {
		if(!straightKeyerKeyIsDown) {
			keyDown();
			straightKeyerKeyIsDown = true;
		}
	} else if(straightKeyerKeyIsDown) {
		keyUp();
		straightKeyerKeyIsDown = false;
	}
}

void initIambicKeyer() {
	// iambic keyer doesn't need to init anything
}

void processIambicKeyerLogic(bool ditPressed, bool dahPressed) {
	int32_t now = HAL_GetTick();

	if(isSending && (now >= sendFinish)) {
		keyUp();
		isSending = false;
	}

	if(nextSend == CW_SEND_NONE) {
		if(ditPressed && (lastSent == CW_SEND_DAH)) {
			nextSend = CW_SEND_DIT;
		} else if(dahPressed && (lastSent == CW_SEND_DIT)) {
			nextSend = CW_SEND_DAH;
		} else if(now > keyReadTimeout) {
			if(ditPressed) {
				nextSend = CW_SEND_DIT;
			} else if (dahPressed) {
				nextSend = CW_SEND_DAH;
			}
		}
	}

	if((now > sendTimeout) && (nextSend != CW_SEND_NONE)) {
		if(nextSend == CW_SEND_DIT) {
			sendFinish = now + keyerConfig.ditTimeMs;
			keyReadTimeout = now + keyerConfig.ditTimeMs*2;
		} else if(nextSend == CW_SEND_DAH) {
			sendFinish = now + keyerConfig.ditTimeMs*3;
			keyReadTimeout = now + keyerConfig.ditTimeMs*3;
		}

		lastSent = nextSend;
		nextSend = CW_SEND_NONE;
		sendStart = now;
		sendTimeout = sendFinish + keyerConfig.ditTimeMs;
		isSending = true;
		keyDown();
	}
}

int32_t getDelta(TIM_HandleTypeDef* htim, int32_t *prevCounter, int32_t mult, int32_t div) {
	int32_t currCounter = __HAL_TIM_GET_COUNTER(htim);
	currCounter = mult*(currCounter / div);
	currCounter = 32767 - ((currCounter-1) & 0xFFFF) / 2;
	if(currCounter > 32768/2) {
		// convert ... 32766, 32767, 0, 1, 2 ... into:
		//               ... -2, -1, 0, 1, 2 ...
		// this simplifies `delta` calculation
		currCounter = currCounter-32768;
	}

	if(currCounter != *prevCounter) {
		int32_t delta = *prevCounter-currCounter;
		*prevCounter = currCounter;

		// debounce or skip counter overflow
		if((delta > -10) && (delta < 10)) {
			return delta;
		}
	}

	return 0;
}

void loopKeyer() {
	uint32_t CWTrainerModeEnterTime = 0;
	int32_t prevCounter = 0;
	displayKeyerSettings();
	// read the initial counter value
	(void)getDelta(&htim2, &prevCounter, MULTI_DELTA_MULT, MULTI_DELTA_DIV);

	for(;;) {
		bool ditPressed = buttonDitPressed();
		bool dahPressed = buttonDahPressed();

		if((ditPressed || dahPressed)) {
			CWTrainerModeEnterTime = HAL_GetTick();
			if(!inCWTrainerMode) {
				enterCWTrainerMode();
				if(keyerConfig.straightKey) {
					initStraightKeyer();
				} else {
					initIambicKeyer();
				}
			}
		} else {
			uint32_t tstamp = HAL_GetTick();
			if(tstamp - CWTrainerModeEnterTime > keyerConfig.ditTimeMs*10) {
				leaveCWTrainerMode();
			}
		}

		if(inCWTrainerMode) {
			if(keyerConfig.straightKey) {
				processStraightKeyerLogic(ditPressed);
			} else {
				processIambicKeyerLogic(ditPressed, dahPressed);
			}
		}

		int32_t delta = getDelta(&htim2, &prevCounter, MULTI_DELTA_MULT, MULTI_DELTA_DIV);
		if(delta != 0) {
			// reset the keyer logic if dit or dah is presset
			leaveCWTrainerMode();
			keyUp();
			changeKeyerSpeed(delta);
			displayKeyerSettings();
		}

		if(buttonKeyerPressed() == BUTTON_STATUS_PRESSED) {
			break;
		}

		HAL_Delay(5);
	}

	leaveCWTrainerMode();
	saveKeyerConfig();
	displayFrequency();
	displayVoltageOrMode(true);
}

void loopBand() {
	ClarMode_t prevClarMode = CLAR_MODE_DISABLED;
	int32_t prevCounter = 0;

	bandMode = true;
	displayVoltageOrMode(true);

	// read the initial counter value
	(void)getDelta(&htim1, &prevCounter, MAIN_DELTA_MULT, MAIN_DELTA_DIV);

	for(;;) {
		if(clarMode != CLAR_MODE_DISABLED) {
			if(switchRitMode()) {
				clarMode = CLAR_MODE_RIT;
			} else {
				clarMode = CLAR_MODE_XIT;
			}

			if(clarMode != prevClarMode) {
				displayVoltageOrMode(true);
				changeFrequency(0, false);
				prevClarMode = clarMode;
			}
		}

		int32_t delta = getDelta(&htim1, &prevCounter, MAIN_DELTA_MULT, MAIN_DELTA_DIV);
		if(delta != 0) {
			changeBand(delta);
		}

		if(buttonBandPressed() == BUTTON_STATUS_PRESSED) {
			break;
		}

		HAL_Delay(5);
	}

	bandMode = false;
	displayVoltageOrMode(true);
}
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
int main(void)
{
  /* MCU Configuration--------------------------------------------------------*/

  /* Reset of all peripherals, Initializes the Flash interface and the Systick. */
  HAL_Init();

  /* Configure the system clock */
  SystemClock_Config();

  /* Initialize all configured peripherals */
  MX_GPIO_Init();
  MX_TIM1_Init();
  MX_I2C1_Init();
  MX_ADC1_Init();
  MX_TIM2_Init();
  /* USER CODE BEGIN 2 */
  init();
  /* USER CODE END 2 */

  /* Infinite loop */
  /* USER CODE BEGIN WHILE */
  while (1)
  {
    loopMain();
    /* USER CODE END WHILE */

    /* USER CODE BEGIN 3 */

  }
  /* USER CODE END 3 */
}

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


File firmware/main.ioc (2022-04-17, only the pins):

Mcu.UserName=STM32F103C8Tx
PA0-WKUP.Signal=GPIO_Output
PA1.Signal=ADCx_IN1
PA10.Signal=GPIO_Output
PA11.Signal=GPIO_Output
PA12.Signal=GPIO_Output
PA13.Signal=SYS_JTMS-SWDIO
PA14.Signal=SYS_JTCK-SWCLK
PA15.Signal=S_TIM2_CH1_ETR
PA2.Signal=GPIO_Input
PA3.Signal=GPIO_Input
PA4.Signal=GPIO_Input
PA5.Signal=GPIO_Input
PA6.Signal=GPIO_Input
PA7.Signal=GPIO_Output
PA8.Signal=S_TIM1_CH1
PA9.Signal=S_TIM1_CH2
PB0.Signal=GPIO_Output
PB10.Signal=GPIO_Input
PB11.Signal=GPIO_Input
PB12.Signal=GPIO_Input
PB13.Signal=GPIO_Output
PB3.Signal=S_TIM2_CH2
PB4.Signal=GPIO_Input
PB8.Signal=I2C1_SCL
PB9.Signal=I2C1_SDA
PC13-TAMPER-RTC.Signal=GPIO_Output

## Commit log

2022-04-17 Move the project from a sandbox repository
    [BOM.csv, af-amplifier.sch, agc.sch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]
2022-04-17 A little clean up
    [hbr-cw-bom.ods]
2022-04-19 Update the silkscreen a little
    [hbr-cw.kicad_pcb]
2022-04-19 Minor change, update the URL in the sheets title
    [af-amplifier.sch, agc.sch, hbr-cw.sch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]
2022-04-19 Clarify that second IF can be other than 9 Mhz
    [if-9mhz.sch]
2022-04-23 Check FreqsWithSpurs[] sort order + bugfix
    [main.c]
2022-04-24 Fix FreqsWithSpurs[] sort order + some minor changes
    [main.c]
2022-04-24 Add a warning that U1 can get a little hot + minor changes
    [hbr-cw.kicad_pcb, hbr-cw.sch]

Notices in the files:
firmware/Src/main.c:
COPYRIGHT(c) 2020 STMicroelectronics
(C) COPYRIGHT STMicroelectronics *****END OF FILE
